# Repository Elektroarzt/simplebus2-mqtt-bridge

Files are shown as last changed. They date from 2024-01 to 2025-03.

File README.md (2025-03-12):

# Simplebus2 MQTT Bridge 

### Table of contents
[1. Overview](#Overview)  
[2. Software](#Software)  
[3. ESPhome](#ESPhome)  
[4. Hardware](#Hardware)  
[5. Mechanics](#Mechanics)  
[6. Disclaimer](#Disclaimer)  
[7. Credits](#Credits) 

## Overview

This project focuses on integrating Comelit intercom systems running the Simplebus2 protocol into a Smart Home, typically equipped with an MQTT broker for information exchange. The following functions have been implemented:

-   Doorbell signal main entrance
-   Doorbell signal apartment door
-   Opening main entrance door
-   Ring-to-Open (automatic opening)
-   WiFi Manager
-   Configuration via Web Interface and MQTT
-   Teach-in of intercom adress
-   OTA updates

Bridge front
Bridge front PCBA
Bridge connector

## Software

### Configuration

A short push on the button (SW1) starts the configuration mode and the bridge opens a WiFi access point named "Config_MQTT_SimpleBus2" for 4 minutes. After connecting to this access point from any device, the following main menu will be shown. If the configured network can't be found or is out of range, the configuration mode will also be launched. The activated configuration mode is signaled by the LED. Alternatively the configuration mode can be started via MQTT.

WiFi manager main menu

After selecting "Configure WiFi" the credentials of the bridge and hardware / firmware configuration can be edited:

WiFi manager configuration

Keep in mind that the ESP32 is not equipped with 5GHz WiFi, only 2,4GHz will work.
The web interface is not supported by every browser in all functions (e.g. firmware update), for best compatibility use Chrome or Edge.

### Hardware tuning
"gain" and "voltage level" are parameters to tune in to the specific installation circumstances depending on cable lenght and resistance of the signal path where gain is the factor the OPV amplifies the line signal at the input and level is the threshold of the comparator before the S2 signal goes to the ESP32s GPIO. A gain of 20 and a voltage level of 600 works good from tests in a building with about 20m cable lenght.

### Open Automation
If selected, the automatic opening of the door after receiving a ring signal is possible. This has to be additionally activated and configured via MQTT. If not selected, the automatic open funcionality is completely disabled.

### Firmware update
The option "Update" in the main menu shows a dialog where a .bin file can be uploaded over the air. This is a good option if the bridge is buried in the switch box. The existing configuration will be kept.

### Adress adjustment
Each intercom unit has its own 8-bits address, which is configured via an 8-way DIP switch during installation. See the interior of your Comelit intercom with the DIP switch in red and translate the bits to your corresponding decimal number, which is usually your appartement or floor number. In some intercoms the DIP-switch can be found on the back, in others you need to open the housing. The address DIP switch is marked S1 and follows LSB logic like in the following table:

 Switch No.| 1 | 2 | 3 | 4 |  5 |  6 |  7 |  8  |
 --------- |:-:|:-:|:-:|:-:|:--:|:--:|:--:|:---:|
 Value     | 1 | 2 | 4 | 8 | 16 | 32 | 64 | 128 |

DIP switch panel

The above intercom for example is addressed to 12.

The adress of the intercom can be easiest teached by pressing the button (SW1) for 3...4s. The bridge will acknowledge with 2x blinking the LED and is then ready to be teached by the next ring that occurs on the bus in the next 3 minutes. The LED will stay on in this time. If the adress has successfully teached in, the LED shuts off and the bridge listens and talks from now on to this specific adress. Alternatively the teach-in process can be started via MQTT. As a third way the choice of the intercom adress can be done manually in the web interface.

### MQTT data structure
**Published topics**

 Topic                          | Values         | Notes
 ------------------------------ |:--------------:| ---------------------------------------------------
 SimpleBus/FloorDoor            | ON             | bell rings on floor door of apartement
 SimpleBus/EntryDoor            | ON             | bell rings on entry door of building
 SimpleBus/Reboot               | ON             | bridge has booted and is listening
 SimpleBus/RingToOpenStatus     | ON / OFF       | 'ring to open' status is on or off
 SimpleBus/RingToOpenOpened     | ON             | is sent if 'ring to open' function opened the door automatically
 SimpleBus/Heartbeat            | ON             | sent every 5min to show online status

**Subscribed topics**

 Topic                          | Values         | Notes
 ------------------------------ |:--------------:| ---------------------------------------------------
 SimpleBus/OpenDoor             | ON             | open the door
 SimpleBus/RingToOpen           | ON / OFF       | activate 'ring to open' (40 minutes default, automatically shut off after bell ring)
 SimpleBus/SetRingToOpenTime    | 1 ... 1440     | activate 'ring to open' for x minutes (max. 24hrs)
 SimpleBus/SetGain              | 2 ... 40       | set gain factor of the amplifier U4 (20 default)
 SimpleBus/SetComparatorVoltage | 100 ... 1500   | set threshold of the comparator U6 to x millivolts, e.g. 600 (default)
 SimpleBus/StartConfigMode      | ON             | start web configuration portal on IP address 192.168.4.1
 SimpleBus/StartTeachIn         | ON / OFF       | ON activates teach-in routine, learns intercom address from the bus; OFF cancels the teaching process
 SimpleBus/Restart              | ON             | restarts the ESP32

### Dependencies
The following components are required to build the firmware. Other versions may also work but are not tested.

 | Component    | Version     | Link                                             |
 | ------------ | :---------- | ------------------------------------------------ |
 | EEPROM       | 2.0.0       | default Arduino                                  |
 | WiFi         | 2.0.0       | default Arduino                                  |
 | Wire         | 2.0.0       | default Arduino                                  |
 | MultiButton  | 1.2.0       | https://github.com/poelstra/arduino-multi-button |
 | Debounce     | 1.2.0       | https://github.com/wkoch/Debounce                |
 | PubSubClient | 2.8         | https://github.com/knolleary/pubsubclient        |
 | WiFiManager  | 2.0.16-rc.2 | https://github.com/tzapu/WiFiManager             |

## ESPhome
If you feel more familiar with ESPhome instead of MQTT give [this companion project](https://github.com/se-bastiaan/esphome-simplebus2) a try. It is based on the hardware of this project and allows for easy integration in Home Assistant. Many thanks to [se-bastiaan](https://github.com/se-bastiaan) for his fabulous work!

## Hardware

The electronics draw power from the bus voltage and require no additional power source. A Seeed Studio XIAO ESP32C3 serves as the controller board.

schematics V2 2

### Expansion pin header J2
For future use this pin header can connect to a piggy-back. The M2.5 hole in the neighborhood can be used to secure a sandwich PCBA.

 Signal Name   | Pin  | Notes
 ------------- |:----:| --------------------------------------------------------------------------------------
 D6            | 1    | GPIO 21 of ESP32 (D6 of XIAO module pinout)
 3V3           | 2    | directly connected to 3.3V plane
 D3            | 3    | GPIO 5 of ESP32 (D3 of XIAO module pinout, outputs PWM signal at boot, strapping pin)
 GND           | 4    | directly connected to GND plane
 
### Debug pin header J3
Meant for debugging, header can be populated optionally. The following signals can be measured against GND:

 Signal Name   | Pin  | Notes
 ------------- |:----:| ----------------------------------------------------------------------------
 D1            | 1    | voltage divider 1, reference voltage of OPV filter stage 1 ('gain' parameter)
 S2            | 2    | cleaned payload signal of Simplebus2
 D2            | 3    | voltage divider 2, reference voltage of comparator ('level' parameter)
 GND           | 4    | directly connected to GND plane

### Filter
In the schematics two filters can be found, one low pass (C5 and R5) and one high pass sallen key active filter with a gain of 2. Between those two filters there is signal amplifier which can be set individually to compensate for a long bus wire. The goal is to filter and amplify the incoming 25 kHz signal.

R1 and R11 are alternative positions to select signal conditioning by hardware (comparator U6) or direct input of the signal into the ESP32. In the second case the firmware should do the signal conditioning via DSP routines or similar. At the moment the DSP option is not implemented in the firmware and is meant for future use, so option "OPV" is default. To change this, desolder R11 and close R1 with a solder drop or a 0Ohms resistor.

## Printed Circuit Board (PCB)

The PCB was designed with KiCAD using through-hole technology (THT) and surface-mount device technology (SMD) to match the limited space requirements. Top layer is 3,3V plane and bottom is GND plane.
If someone is interested in a complete bridge including all parts (PCBA, ESP32, housing, etc.) you can contact me under elektroarzt@digital-filestore.de.

PCB Layout front

## Mechanics

The entire electronics assembly fits into a flush-mounted switch box, resulting in a streamlined enclosure. The latch was designed as a snap closure, eliminating the need for additional mechanical components beyond the housing shells.



A second option for the housing is a DIN rail enclosure. For this, I have created an alternative bottom shell with a builtin clip that can be directly clicked onto a DIN rail. It should not be printed in PLA, use a somewhat flexible filament like PETG. Otherwise, there is a risk of cracking the clip if released from the DIN rail again. The top part of the housing is identical to the flush-mounted version.

Bottom DIN Rail Mount
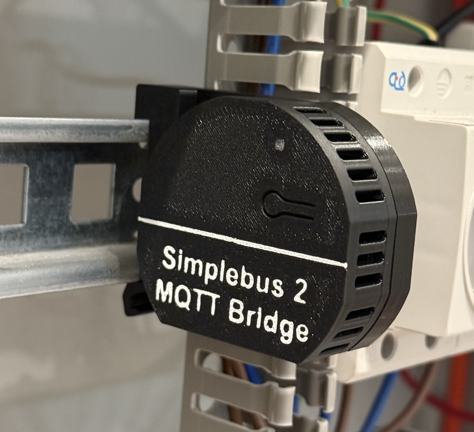
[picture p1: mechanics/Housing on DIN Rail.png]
Bottom DIN Rail Mount


### Antenna
The antenna is mounted inside the housing with adhesive tape. A small cable channel exists for the antenna cable within the housing. Be careful while inserting the PCB in the housing not to shear off the antenna cable if it is not inserted properly into the cable channel.

Bridge Antenna

### USB connector
The USB-C socket is externally routed, allowing for easy firmware updates.

### LED and button
The onboard LED features a simple light guide, making it visible externally when the housing is closed. The onboard button is operated with a small axis embedded in the housing.

### Housing
The housing was designed in Autodesk Fusion 360 and 3D-printed in three colors on Bambu Lab P1S printer:
-   LED diffuser: transparent filament
-   Housing: black filament
-   Labeling: white filament



For the type of filament every material is suitable that has low stringing tendency. PETG works for me without needing supports. 0.2mm layer height does a good job on a 0.4mm standard nozzle.

Bambu Lab project

## Disclaimer
> :warning: **WARNING**: You may only **USE THIS PROJECT AT YOUR OWN RISK**. The
  information provided is meant to be helpful but may contain errors or may be
  misinterpreted. Neither myself nor any of the contributors to this project
  provide any warranty or will assume any responsibility for any damage you
  cause yourself or others by using this project.

## Credits
The project originated from the excellent foundational work on the Simplebus2 protocol by [plusvic](https://github.com/plusvic). These fundamentals will not be reiterated and can be found [here](https://github.com/plusvic/simplebus2-intercom).

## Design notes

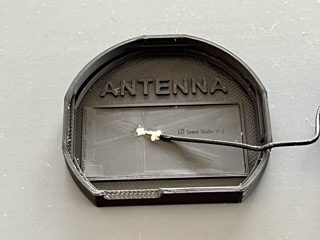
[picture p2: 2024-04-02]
hardware/Bridge antenna.jpeg

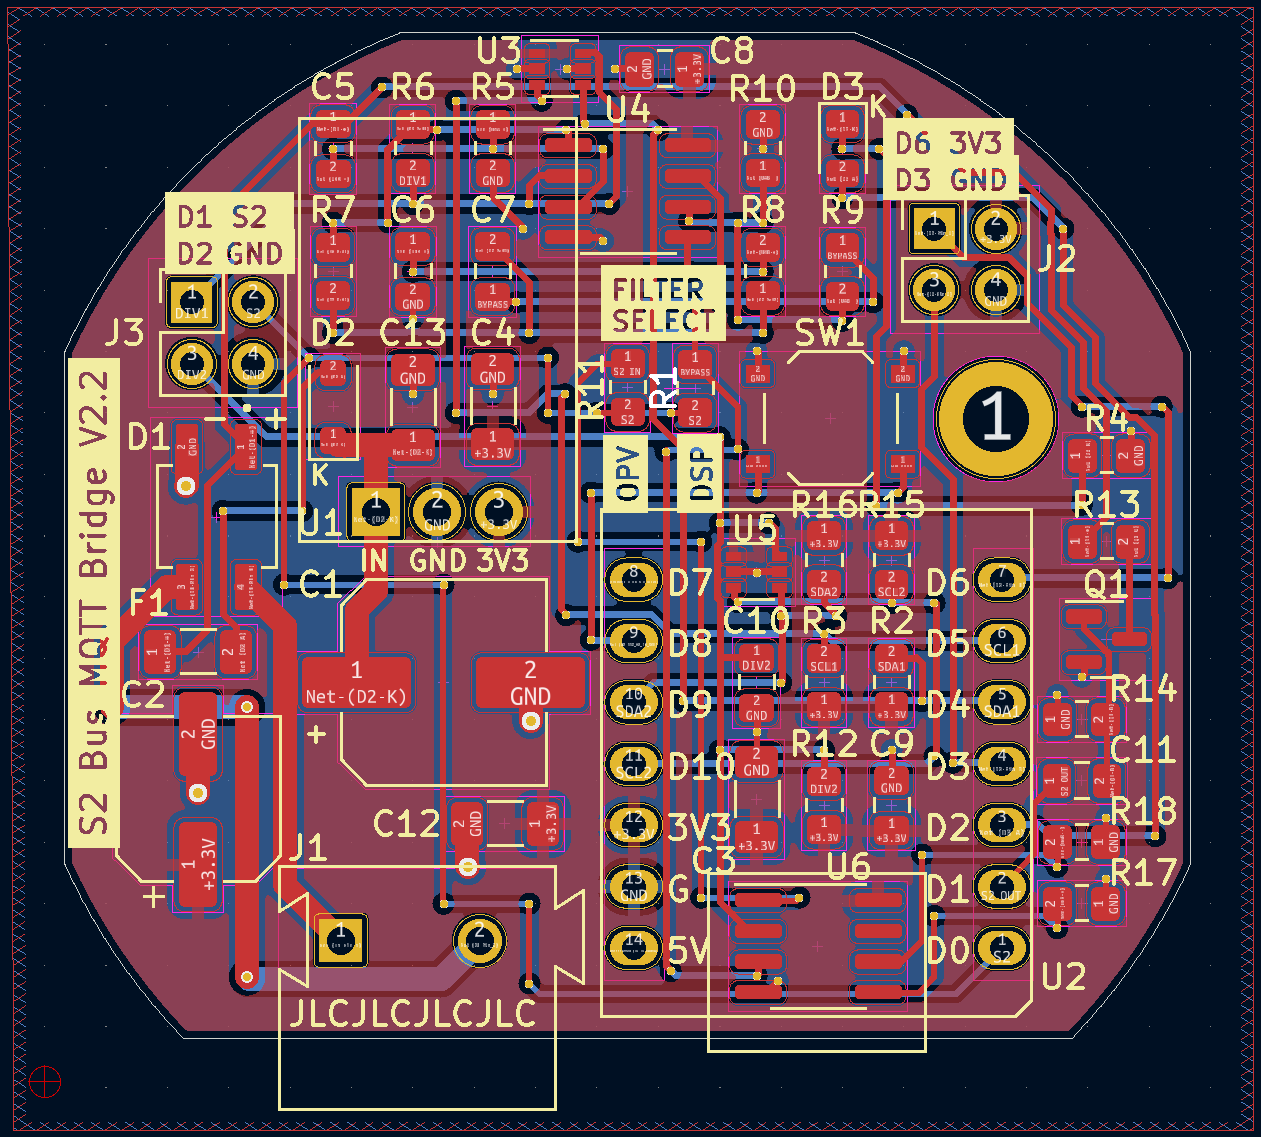
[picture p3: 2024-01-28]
hardware/Layout front V2.2.png

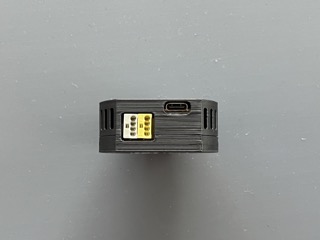
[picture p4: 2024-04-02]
hardware/Bridge connector.jpeg

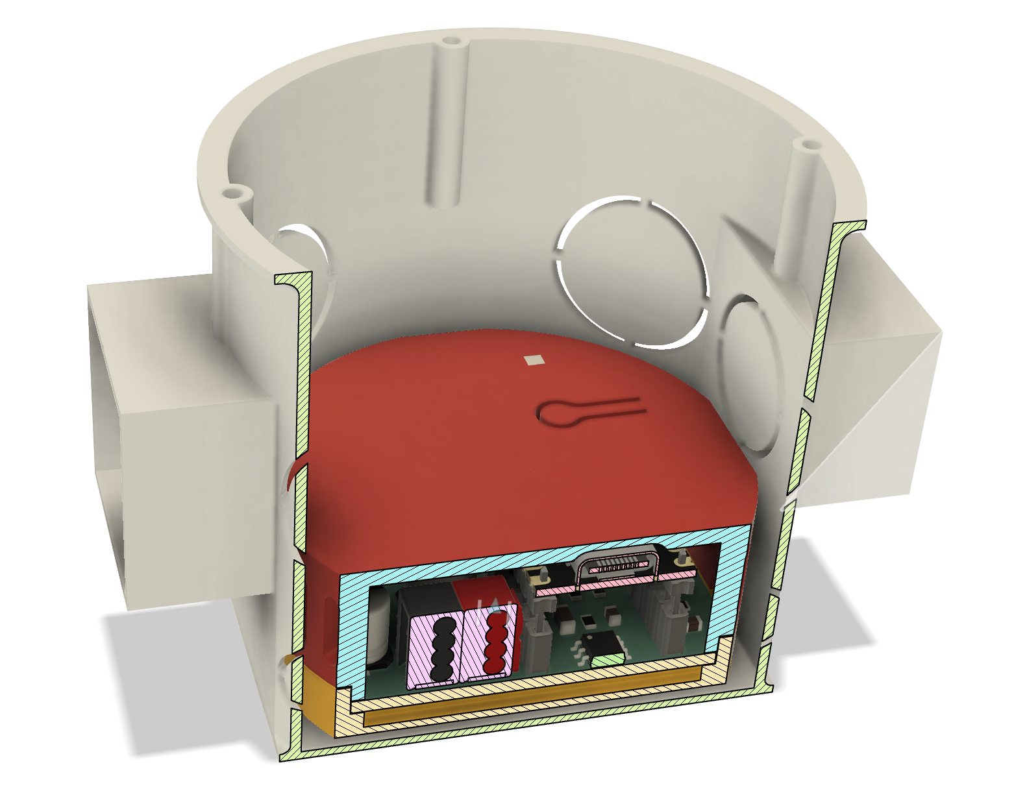
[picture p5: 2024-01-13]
mechanics/Housing in flush mounted switch box.png

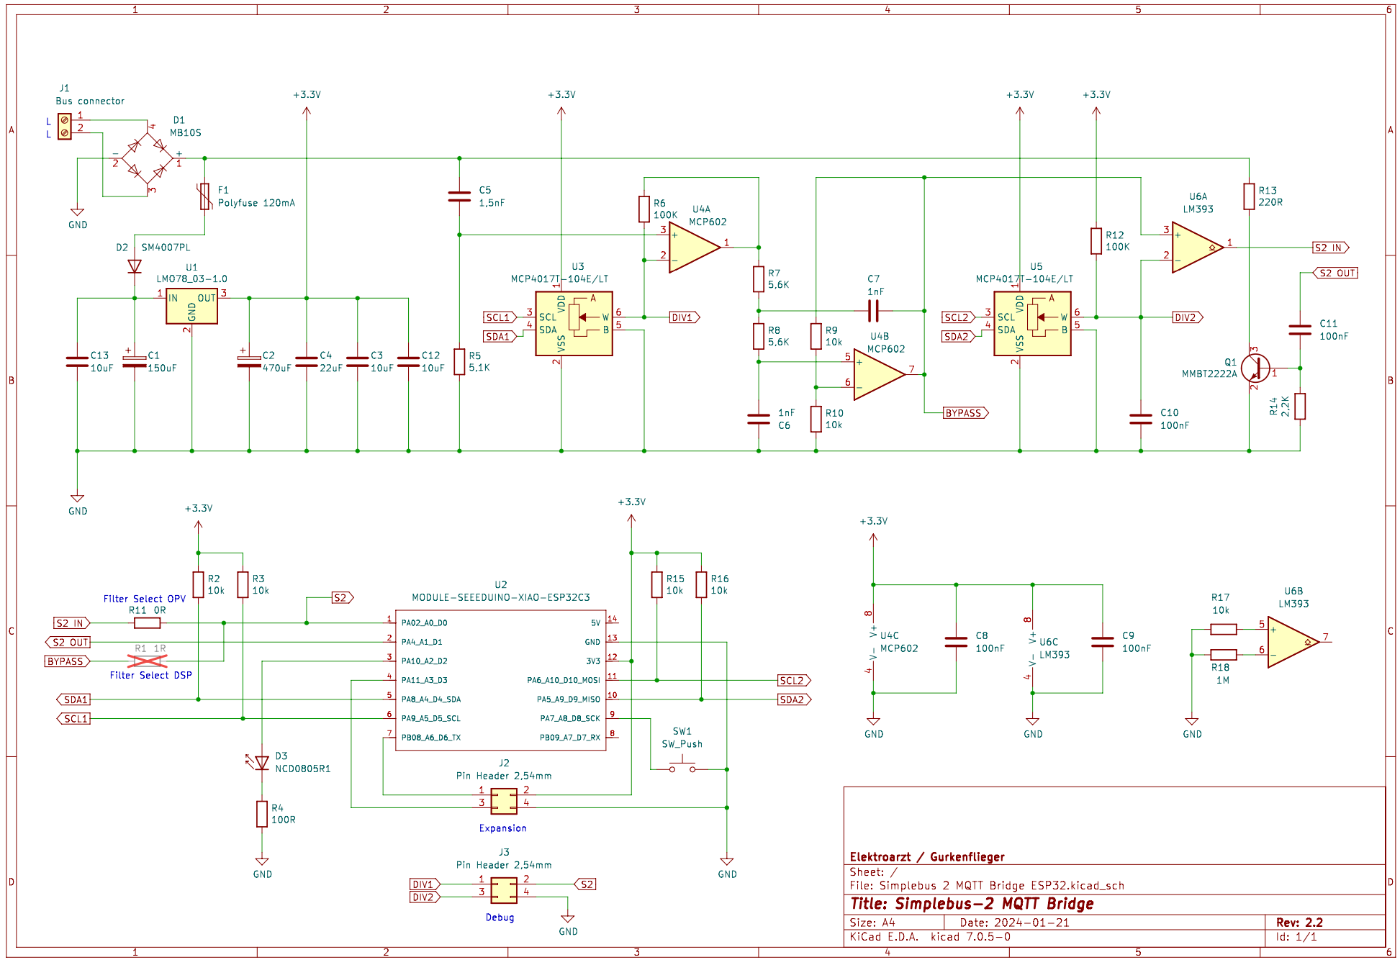
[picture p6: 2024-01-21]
hardware/schematics V2.2.png

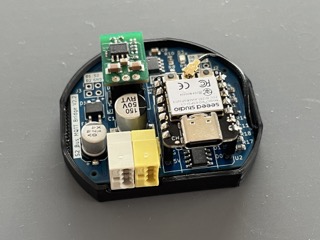
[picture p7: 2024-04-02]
hardware/Bridge front PCBA.jpeg

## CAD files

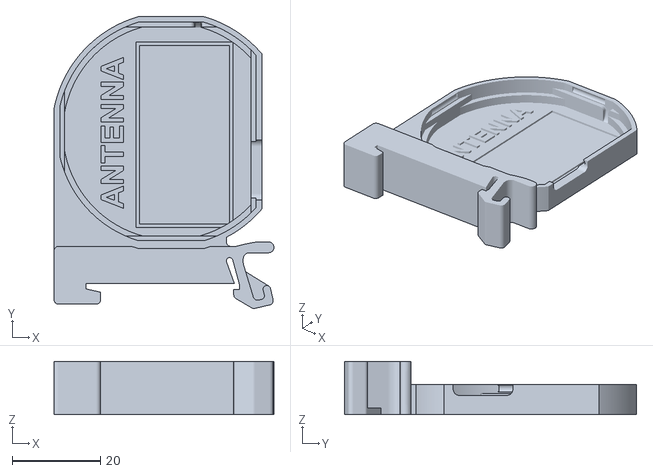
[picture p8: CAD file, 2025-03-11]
mechanics/Housing Bottom Shell DIN Rail Mount.stl
49.7 x 66.1 x 12.0

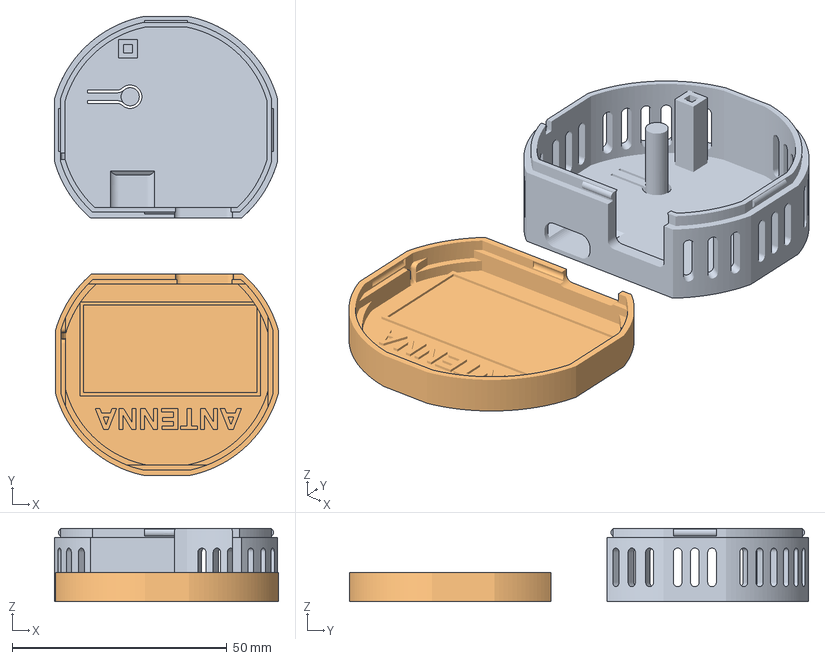
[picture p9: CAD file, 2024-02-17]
mechanics/Simplebus2 MQTT Bridge Bambu Lab Project.3mf
52.2 x 107.0 x 17.1 mm
Top Shell
Bottom Shell

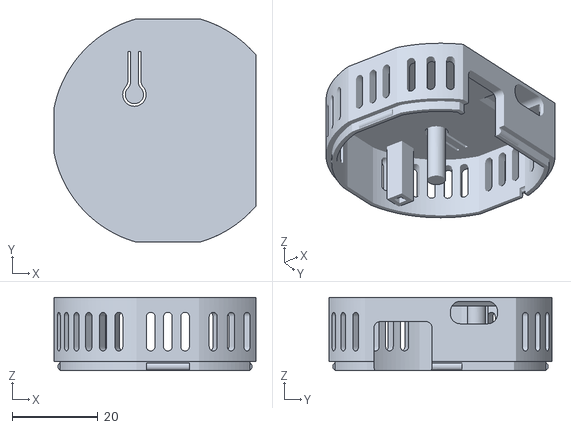
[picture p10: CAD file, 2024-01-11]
mechanics/Housing Top Shell.stl
47.0 x 52.0 x 17.1

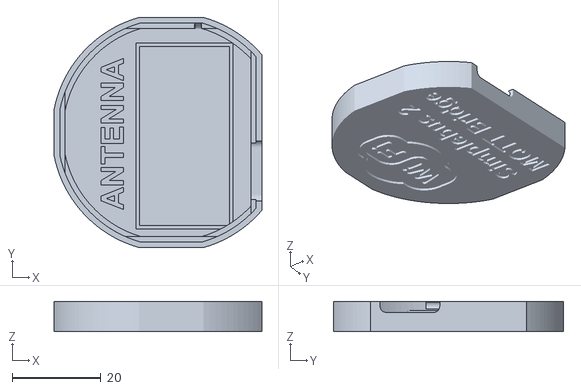
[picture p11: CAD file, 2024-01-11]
mechanics/Housing Bottom Shell Flush Mounted.stl
47.0 x 52.0 x 6.80

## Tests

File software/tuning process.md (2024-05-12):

# Tuning process for gain and threshold parameters

If you have no oscilloscope to measure the telegram signaling, you are some kind of blind and it could get a game of testing to find out the right combination of gain and threshold for your specific environment. In this case I would go this way:

1. Be sure to have an easy way on your mobile phone to tune the parameters gain and threshold via MQTT and to see the recognition of the bell telegrams. I used Node Red, but you could also use an MQTT analyzer app on your phone.

2. Check if you see a heartbeat on MQTT topic SimpleBus/Heartbeat after powering the bridge to secure your MQTT chain is online before making tests.

3. Start your tests at the floor door (apartment). Stand at the bell switch and make tests with your mobile phone in the hand to tune the parameters after each failure. For the start tune to 5/200 (gain/threshold) and go up with the threshold from 200mV up to max. 1000mV in steps of 50 for each test. If you find no recognition on MQTT topic SimpleBus/FloorDoor, start again at threshold 200 with gain rised in steps of 5 and so on until you get ON on MQTT.

4. Now make some tests at the entry door (MQTT topic SimpleBus/EntryDoor). The cable length is much longer, so the damping is higher for the telegram. The gain has to be also a bit higher for reliable recognition probably. So if you encounter a working bell signal on the floor door, it could be you have to add some gain for the entry door.

5. As a rule of thumb, the higher the gain is set, the higher you have to set the threshold, as the noise on the line is always amplified too (signal/noise ratio).

With this setup you should be able to find the right setting within short time.

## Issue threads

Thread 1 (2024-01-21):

PCBA

Elektroarzt, 2024-01-21:
Upload is done for now. If someone is interested in a complete bridge including all parts (PCBA, ESP32, housing, etc.) you can contact me under elektroarzt@digital-filestore.de.

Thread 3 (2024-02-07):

Adding support for audio/video

sashahilton00, 2024-02-07:
Hi,

Opening an issue here after @Elektroarzt and I emailed for a bit. Relevant parts of the the email trail pasted below:

> @sashahilton00 - Out of interest did you get anywhere with the audio/video component? From what I’ve read it’s some sort of composite video, I’m wondering if it would be possible to add a decoder chip and create an RTSP server on the device when the camera is activated, then send the server address over MQTT to enable a remote feed.

> @Elektroarzt - Concerning the video option, we (Gurkenflieger and me) did not investigate yet but I’d love such a feature. This would be a Piggy-Back on the existing PCB or a complete new design with maybe 4 layers instead of 2, as the current design is at the lower end of JLCPCBs 2 layer design rules in terms of  trace width, micro vias and so on.

> @sashahilton00 - For the audio/video I’ve done a small amount of reading - it seems to be using some sort of analog audio and NTSC/PAL video on the bus from what I can tell. The latter would need a dedicated decoder chip that fed digital out into the ESP32 via i2s, need to investigate the audio. The comelit-simplebus1 project on GitHub may offer some insight, as I’d be surprised if they’d changed much between the two.
You may be right about the 4 layers being needed, though it would be good to keep it as 2 to keep costs down and allow people with a home setup to manufacture it. Also one would need to give some consideration to power draw as I’m sure video decoding will use a fair bit more than the current system.

> @Elektroarzt - From what I read, the video feature would bring necessity for an external PSRAM attached to the ESP, as the 400kB or so would’t be sufficient to store a single frame in the onboard RAM.

> @sashahilton00 - Both https://www.espboards.dev/blog/esp32-soc-options/ and https://gist.github.com/sekcompsci/2bf39e715d5fe47579fa184fa819f421 seem to suggest that the ESP32-S2 has both an internal ADC and DAC. My PCB skills are a little rusty, but looking at a similar project (https://github.com/vvigilante/comelit-simplebus1), it looks as though that’s what vvigilante has done - used the internal ADC/DACs for the audio with a potentiometer to allow for manual adjustment (could be neat if this were a digital potentiometer) - I don’t have an oscilloscope to measure, but vvigilante mentions that peak to peak amplitude is approximately 2.5v.
My thinking is that one could incorporate the analogue write/analogue write enable circuitry into your design, and at the same time switch from the Seeed Studio XIAO ESP32C3 to something like the Adafruit QT Py ESP32-S2 (https://shop.pimoroni.com/products/adafruit-qt-py-esp32-s2-wifi-dev-board-with-ufl-antenna-port-stemma-qt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), which keeps the xiao footprint, type c and external antenna, or equally one could move to having the esp32 soldered directly by JLC or similar (eg. ESP32-S2-MINI-2U-N4), and including the type C connector manually.
One thought I did have if one goes down the soldered board route, is to make the type C connector (and possibly the bus connector) vertical, eg. https://jlcpcb.com/partdetail/Xunpu-TYPEC_300ABCP16H175/C5454935, as when in the standard euro switch box the USB would then be accessible without needing to remove the device for firmware updates.
If one went down this route it looks as though esp-adf (https://github.com/espressif/esp-adf) would provide the necessary support to implement two way audio streaming (have a look at the following for an RTSP implementation: https://github.com/espressif/esp-adf/tree/48dea7711391e0abf00c65aca18557572fc5189a/examples/protocols/esp-rtsp), where a ring of the bell would set up the rtsp server and send the ringing MQTT message, whilst the client if a microphone is available can send an RTSP address in an MQTT message for the microphone stream. There’s also RTC/VoIP possibilities if that’s preferred.
If that sounds of interest and you’re happy to modify the PCB to use an S2 variant chip with the ADC/DAC wired up to the bus, I’d be happy to get JLC to make me up a board and see if I can write some software to get two way audio working.

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

sashahilton00, 2024-02-07:
@Gurkenflieger if you have any thoughts they would be most welcome.

Having done some more reading up today on the ESP32 and video capture, it looks as though it will be a stretch to manage it. If you have any insights as to the video format that Comelit is using that would be great, everything I read suggeests it's NTSC/PAL.

With that in mind, the ESP32 has support for the ESP32-CAM module, which seems to support an 8 or 16 bit DVP image sensor. There are also low power PAL/NTSC decoder chips available (eg. TVP5150AM1), which output the same 8-bit YCbCr 4:2:2 as the esp32 cam to my knowledge. The esp32 apparently has a 20MHz limit on the pixel clock from the sensor, whilst PAL/NTSC requires a 27Mhz clock, though after a bit of searching theres [this](https://esp32.com/viewtopic.php?t=2564#p12309) rather neat workaround by the looks of it from `ESP_igrr`, which uses a frequency divider and two octal latching ICs to convert the 8-bit 27Mhz stream into a 16 bit 14.5Mhz stream, essentially halving the overhead.

However, this is where I'm not sure the video component is solvable - the raw video stream is too large to stream (as highlighted [here](https://github.com/wooky/esp32-analog-video-over-wifi)), if you've got any thoughts as to whether this is doable without building a fully fledged streaming SBC, I'm all ears, though dealing with video decoding/encoding feels like it's getting a bit beyond the scope of a simple retrofit device.

Elektroarzt, 2024-02-08:
@sashahilton00 I can say that the video option would be out of my comfort zone concerning the RF layout and debugging. If you like to contribute and go for a prototype with the audio part, you are welcome. I then could integrate in the PCB, if tests run ok.

Elektroarzt, 2024-09-07:
Closed due to inactivity

Closed 2024-09-07.

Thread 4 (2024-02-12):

I2C communication not working correctly

Elektroarzt, 2024-02-12:
The voltage dividers for the OPVs are programmable via I2C potentiometers. In the current firmware the communication on bus 1 and 2 seem not to work.

Gurkenflieger, 2024-02-13:
Fixed in recent commit

Closed 2024-02-13.

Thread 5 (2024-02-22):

Recognition of entry door ring not working

alexdetsch, 2024-02-22:
I have the problem that the doorbell at the front door is not recognized. However, ringing the doorbell at the apartment door and opening the front door works without any problems. I have already checked the signals with Elektroarzt and they should actually be correct. The message in the signal from the front door is also correct (my intercom system also rings). Following is a picture of the oscilloscope.
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

Yellow is the signal in front of the comparator, blue behind it (at S2). The firmware is from 2024-02-07 15:19. The gain is currently set to 80 (much too high actually, I know), the voltage threshold to 200. I have tried gain in the range of 7-80 and voltage threshold of 100-200, as well as with and without activated "filter"-checkbox.

Gurkenflieger, 2024-02-23:
This could be a Timing Problem. Habe you tested RingToOpen? Does it work. I can imagine that the mqtt send command is too early and the power is insufficient directly after the ring command.

alexdetsch, 2024-02-23:
I tried that now, but it didn't work (both with and without attached loudspeaker).
All my other attempts the other days were without the loudspeaker handheld, so I think there wasn't much of a voltage drop while ringing. And I don't think there should be any difference between the front door and the apartment door from the voltage drop regard?

Gurkenflieger, 2024-02-23:
You can debug the Software with an attached pc in the stdout. There should be debug messages which are commented out. They print the single recognized bits. Is it possible to comment them in ?

alexdetsch, 2024-02-23:
I can try, but unfortunately I can't find all the dependencies. It would be nice if you could add a few more details about which specific library is meant (GitHub link?). Currently I can't find the debounce library.

Gurkenflieger, 2024-02-23:
Sry here is the github link of the debounce lib.
 https://github.com/wkoch/Debounce i'm using v1.2

alexdetsch, 2024-02-23:
Ok, the address and msgCode is recognized correctly:
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
So it's probably an easy fix :) I'll debug a little bit

alexdetsch, 2024-02-23:
Yes, I had everything correct.
The bug is in [L464](https://github.com/Elektroarzt/simplebus2-mqtt-bridge/blob/main/software/main.cpp#L464). When messageCode 48 is sent, there is just a break. I removed it and now it works flawlessly. Maybe it worked for you because you have an other Intercom? My entry door intercom send msgCode 48 (as shown in the image above) instead of 50.

Gurkenflieger, 2024-02-23:
Thanks, of course intercoms without a screen hava an other message.  I will update the code soon. Thanks for the work!

Elektroarzt, 2024-02-23:
By the way ... what gain and threshold values are working for you after the fix?

alexdetsch, 2024-02-24:
Currently I still have 80 gain and 150 voltage threshold cause I didn't bothered with them anymore after it worked finally. But initially the two functions ring on apartment door and open entry door worked with the default values.

I already built the module behind my Intercom, so its kinda complex to get it in configuration mode when I'm not wrong (which eliminates the advantage of remote firmware updates for me, because I still need physical access).
Or is there currently a way to activate the configuration mode remotely? I'm thinking about implementing an activate-conf-mode-over-mqtt-feature, what do you think about that?

Elektroarzt, 2024-02-24:
There is no way for remote activation currently. What do you think of conf-over-MQTT instead of activating the conf mode or both? Of course one has to initially config via Web Interface. But to change some values it could be cool to have all parameters at MQTT-hand.

alexdetsch, 2024-02-24:
Above I meant to activate the conf mode over MQTT. I also implemented it in my fork already to tinker around (but didn't tested it yet cause of laziness to take the intercom apart again). But you're right, having the config values (gain, threshold, filter) on hand via MQTT is also a very nice idea! (don't know why I didn't think of this very obvious idea 😶‍🌫️)

Gurkenflieger, 2024-02-25:
Activating the config mode with mqtt is a good idea 👍.

richardneitzke, 2024-02-28:
> it worked all the way down to gain=1 and threshold=1 and at this point I'm not sure if the values are set correctly (I had 8 tries from gain=80 and threshold=200)

@alexdetsch maybe your settings have no effect at all, that’s what I ran into (#7)

Gurkenflieger, 2024-02-29:
Maybe the resistors are stuck at a wrong state and the reset does not work as intended. I can add a send command to reset the resistors. Will update the code soon.

Gurkenflieger, 2024-04-02:
It should work now with 600mV comparator voltage and 20 Gain. Can you test it?

Closed 2024-04-02.

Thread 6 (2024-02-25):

Add setup with MQTT and start webconfig with MQTT

Gurkenflieger, 2024-02-25:
-Add setup of filter, gain and comparator voltage with    mqtt.
-Start Webinterface with MQTT.
-Improve MQTT send command.

Elektroarzt, 2024-02-25:
If you put your hands on the web interface function and can reproduce it, could you have a look at the exit procedure? From time to time I experience the LED not going off after changing parameters and leaving the web interface via save button. I then shortly disconnect bus power to return to normal operation. Could be critical, if the config is started by MQTT and can't be exited remotely.

Gurkenflieger, 2024-04-02:
Now implemented with improved MQTT commands.

Closed 2024-04-02.

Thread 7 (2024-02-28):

Changing the level/threshold parameters has no effect

richardneitzke, 2024-02-28:
I'm using a V2.2 bridge provided by @Elektroarzt and so far I haven't managed to make things work. I switched to the latest firmware (3b4bd75) for debugging and noticed that the "level" (`compVoltLvl`) parameter does not seem to have any effect on the comparator reference voltage (D2).

The level parameter appeared to be working with the original firmware that shipped with the bridge. I haven't actually measured it but changing it seemed to have an effect on the detection quality.

I measure an average of about 1.03V on D2, no matter whether the level is set to 150mV (`setPotValue(6)`) or 500mV (`setPotValue(22)`):

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

richardneitzke, 2024-02-28:
I also checked whether changing the "gain" parameter has any noticeable difference on the comparator input (measured at the "R1-1" pad) and it seems like that isn't the case either. The level of the signal at that pad is about the same when I set gain to 5 vs. 50.

This indicates that this isn't specific to the "level" parameter but rather an issue with the connection to the MCP4017 potentiometer?

richardneitzke, 2024-02-29:
@Gurkenflieger I only have a very vague idea of what I'm doing but I made some changes and the voltage on D2 is now in the ballpark of what I configure it to. I think this is still not the correct reset sequence (it should have another start bit after the 9 "1" bits).

In `setupI2C(int)`:

```C++
Wire.begin(sdaPin, sclPin, I2C_FREQ);
Wire.beginTransmission(0b111111111);
Wire.endTransmission();
```

At the end of `setPotValue(byte)`:

```C++
Wire.end();
```

Gurkenflieger, 2024-03-01:
Which version did you use? already implemented an almost similar fix in the recent Version.
Wire.beginTransmission(0xFF);
 Wire.endTransmission();
 this worked with my stuck Resistor.

richardneitzke, 2024-03-02:
> Which version did you use? already implemented an almost similar fix in the recent Version.

I referenced the commit in my initial message, seems like it contained the fix you referenced.

> can you test this?

I'll test it later, the code I posted seemed to do the trick so I assume yours will also work 👍

Gurkenflieger, 2024-04-02:
Wirh the new commit the values will change.

Closed 2024-04-02.

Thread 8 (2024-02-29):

No pulses on S2

richardneitzke, 2024-02-29:
When I ring the floor door and observe the comparator input ("R1-1") and the payload signal (S2 debug pin) I don't see a clean PWM signal on S2. Right now, the firmware is unable to decode messages from signals like this. I could try to make this work in software but I was hoping that we can find a way to have clean signals for installations like mine.

Here's the full signal, C1 being the payload signal and C2 the comparator input as reference. Notice how the burst is not oscillating cleanly on the comparator input and barely oscillating on S2:

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

| Two bursts as an example | Closeup of a single burst |
| -- | -- |
| 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 | 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 |

Here is a closeup of the acknowledgement bursts (presumably by the main unit). These are basically perfect. I optimized my gain/threshold values for these pulses (raising them to about 500mV at the comparator input as recommended by @Elektroarzt):

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

 (Sorry for the photos, my scope stopped accepting USB drives...)

Gurkenflieger, 2024-03-01:
Have you tried disabling the Filter?

richardneitzke, 2024-03-02:
> Have you tried disabling the Filter?

No, I haven't tried to bypass the HW filter.

> I uploaded a new version. Can you test this one?

The measurements above were taken on a [modified FW](https://github.com/Elektroarzt/simplebus2-mqtt-bridge/issues/7#issuecomment-1971938850) that was almost identical to the new version (the I2C connection to the MCP4017's seemed to work). I don't think using the new version would make a difference but I can try?

> Does your intercom has a screen?

Yes 👍

> I Also will change the interrupt detection from rising to Falling or Change. This could fix your problem!

Yes, that would work. I was hoping we would find a HW fix which results in a regular signal. Working around the irregular signal in SW is probably less reliable than adjusting the HW so that it either serves clean bursts or no bursts at all on S2?

Gurkenflieger, 2024-03-02:
Not the hardware filter but the software filter in the webconfig. You can also turn down the Gain. This should help alot!

richardneitzke, 2024-03-02:
Yes, I turned off the software filter 👍 This issue is mostly about the hardware though, wouldn't it be more desirable to ensure a clean signal as opposed to working around the irregular signal in the firmware?

> You can also turn down the Gain. This should help alot!

There's a fairly big delta in amplitude between the signal from my intercom and the signal from the main unit. I tweaked the gain value so that I can reliably detect signals from the main unit (as seen in the last image of my initial post). If I reduce the gain I would most likely lose the ability to detect these, right?

Gurkenflieger, 2024-03-02:
Ah you should tweak the gain and comparator voltage not on the acknowledge bursts but on the message itself. The acknowledge is always way higher than the message itself. The software only looks for the message not the acknowledge. Which values did you set for the gain? The could be way too high and induce noise.  Try gain 10 and 200mV. Then you can also use the debut messages and comment thwm in.

richardneitzke, 2024-03-02:
> Ah you should tweak the gain and comparator voltage not on the acknowledge bursts but on the message itself. [...] The software only looks for the message not the acknowledge.

I realise that, but the message I measured above comes from my intercom. I would like to be notified of messages from my intercom (in case somebody rings at my apartment door) as well as messages from the main unit (in case somebody rings at the house door downstairs). As you write, there is a big difference in amplitude between the two. Yet, I want to be able to decode both. If I reduce the gain, wouldn't I lose the ability to decode messages from the main unit (which are currently decoded perfectly, see the acknowledgement bursts which come from the main unit in the last image)?.

>  The acknowledge is always way higher than the message itself.

At least in my installation that doesn't seem to be the case when the message comes from the intercom itself. I assume the acknowledgement comes from the main unit (which is why the amplitude is much lower in that case).

> A clean PWM is not necessary. The software measures time between too high signals (in future release between too pin changes). The measured time (pause time) determines if it's a 0 or 1 or a start bit.

Huh, this puzzles me. Could you please elaborate? If I understand the current iteration of the software correctly it _does_ rely on a clean PWM signal. My understanding is that the software would interpret a noisy PWM burst such as the one I posted above ("Closeup of a single burst") as a "0" because the burst itself contains a ~2.5ms "pause" between two rising edges.

There surely are ways to clean up the signal in software but I would only go there if there are no ways to improve the signal quality itself.

Gurkenflieger, 2024-03-02:
No only if the filter is enabled a more or less clean PWM signal is necessary. Without the software filter it measures the time between two bursts or the time between two high pins. The PWM itself does not matter i just need a high signal.

richardneitzke, 2024-03-02:
> No only if the filter is enabled a more or less clean PWM signal is necessary. Without the software filter it measures the time between two bursts or the time between two high pins. Its just ja timer that resets if a high signal is detected. If the timer reaches a certain value it determines if its a 0 or 1 or start bit.

This is a 3ms burst, by itself it shouldn't be decoded into a 0/1. My understanding is that the current firmware measures the pauses between rising edges, that's what you describe as well (_"a timer that resets if a high signal is detected"_). This burst has a rising edge at the trigger point and about 2.4ms after the trigger point. Wouldn't the firmware decode this as a 0-bit because the pause is between 2ms...4.9ms?

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

richardneitzke, 2024-03-02:
Just to reiterate: I realize that this can be fixed in software by introducing stricter timing requirements and also taking falling edges into account. But to me the underlying issue appears to be on the hardware-side and we’d be better off fixing it there instead. It seems like that would result in a more stable system overall.

Gurkenflieger, 2024-03-02:
Now i see your problem. Where is the Bridge connected? Because your Signal is so high its near the main unit and not the Screen? Try turning down your Gain and turning up your comparator voltage to 600-800mV. I will revisit the problem.

richardneitzke, 2024-03-02:
I think there’s still a misunderstanding, so I’ll just repeat 😅

I recorded this when my floor door was rung. The message comes from the intercom unit itself. The acknowledgement comes from the main unit.

The messages from the main unit are decoded fine but I also want to decode the messages from my intercom unit. If I reduce the gain and increase the comparator voltage I won’t be able to decode the messages from the main unit anymore.

Elektroarzt, 2024-03-03:
This is your measuring setup, right?
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

Gurkenflieger, 2024-03-03:
Now i understand your Problem. I dont know if there is an easy hardware solution for the comparator. Like i said the PWM is not necessary and we can easily find a software fix. We can also bypass the comparator which seems to be too slow and check the raw signal with the esp. Bypassing the comparator is already considered in the current design but we have to write software to check the signal at the analog in.

richardneitzke, 2024-03-03:
> This is your measuring setup, right?

@Elektroarzt Yes, that's it 👍

> Can you post the signal from the entry door which needs to be amplified? Which gain did you set?

@Gurkenflieger here's what the signal from the entry door looks like (gain = 1, compVoltLvl = 250):

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

Gurkenflieger, 2024-04-02:
I updated the Code and now my floordoor and on some other intercoms are now working correctly. Can you try it out with the latest firmware. You have to set Gain 20 and 600 mV.

Elektroarzt, 2024-05-28:
Have you seen the how-to for the tuning process I wrote? See [here](https://github.com/Elektroarzt/simplebus2-mqtt-bridge/blob/7138530772fd946b185f70a6c94b0642a4dc3e89/software/tuning%20process.md).

richardneitzke, 2024-05-28:
I had a look at the commits that have been made since I raised the issue and maybe I'm missing something but I don't see any changes that address the underlying issue I described [here](https://github.com/Elektroarzt/simplebus2-mqtt-bridge/issues/8#issuecomment-1974823521)? So I don't think tuning the gain/threshold values would do any good here?

Elektroarzt, 2024-05-29:
The behavior you described is normally caused by too high gain, it's not an issue in the firmware in my opinion. Which gain did you set in the given picture? I can reproduce this beginning from gain around 30. Did you follow the tuning sequence as described?

Gain set to 25:
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

Gain set to 30:
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

richardneitzke, 2024-05-29:
Ah thank you, that makes sense! I don't recall the gain value I used for the picture but I will try tuning it again 👍

Elektroarzt, 2024-05-29:
I saw you've set 1 as gain in one post. This was never an allowed value but was not restricted by the legacy firmwares. Be sure to have the newest firmware running before doing the tests, as it checks for the correct range.

richardneitzke, 2024-05-29:
> I saw you've set 1 as gain in one post. This was never an allowed value but was not restricted by the legacy firmwares. Be sure to have the newest firmware running before doing the tests, as it checks for the correct range.

Thanks for the hint 👍 I assume that most of my settings back then did not actually apply correctly due to the I2C bug. I will try tuning it again on the latest FW.

Closed 2024-04-26.

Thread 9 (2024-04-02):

Your help is needed for standard values for gain and threshold

Elektroarzt, 2024-04-02:
From experience, it was a good decision to equip the values for gain and threshold with digital potentiometers, as there is a signal dependency on every specific installation regarding attenuation on the bus wires. After extensive testing, standard parameters have crystallized for this purpose. With the values of gain at 20 and a threshold of 600mV, the up to now considered systems are operational. If you have a bridge up and running, please be so kind as to reply to this thread whether these settings also work for you, so that we can confirm these values as standards for the community. If they do not work, please write back your working values.
Both can be set easily with the new MQTT commands in the latest firmware or in the web interface (see readme).

Thanks for your support! :wave:

alexdetsch, 2024-04-13:
For me 20/600 is working fine with the latest firmware :)

LaurensdeGraaff, 2024-05-01:
The default is not working for me, I'm still trying to get a working config. Do you have any tips how to find them without a oscilloscope? I flashed it with esp-home, if you have a .bin file I will gladly test the values on the MQTT firmware.

Elektroarzt, 2024-05-02:
The config values 20/600 are tested and working with the Arduino firmware. If you have flashed a 'custom' firmware, there is a completely different algorithm decoding the bus signals. So likely other standard parameters have to be chosen. The software developer could help out maybe. I will upload the current bin file shortly if you want to get back to the Arduino firmware.

se-bastiaan, 2024-05-07:
I've recorded the values received by the bridge on the bus during a single day. The 20/600 values do allow me to receive messages, but except for a few case none of those were sent by the switchboard at the front door:

```
20:43:08 {"code": 16, "addr": 25}
20:43:07 {"code": 17, "addr": 25}
19:49:08 {"code": 21, "addr": 16}
19:48:07 {"code": 16, "addr": 16}
19:47:12 {"code": 21, "addr": 16}
19:45:42 {"code": 16, "addr": 16}
19:36:03 {"code": 21, "addr": 16}
19:34:53 {"code": 16, "addr": 16}
19:28:27 {"code": 21, "addr": 16}
17:41:13 {"code": 21, "addr": 29}
17:25:22 {"code": 18, "addr": 9}
17:25:18 {"code": 16, "addr": 9}
17:25:11 {"code": 17, "addr": 9}
17:12:09 {"code": 18, "addr": 45}
17:12:02 {"code": 16, "addr": 45}
17:11:59 {"code": 17, "addr": 45}
16:13:42 {"code": 21, "addr": 41}
16:12:34 {"code": 16, "addr": 41}
16:10:42 {"code": 16, "addr": 2}
16:10:36 {"code": 21, "addr": 2}
16:07:05 {"code": 63, "addr": 255}
16:06:54 {"code": 18, "addr": 31}
16:06:51 {"code": 16, "addr": 31}
16:06:47 {"code": 49, "addr": 31}
16:06:47 {"code": 17, "addr": 31}
15:23:21 {"code": 16, "addr": 8}
15:23:08 {"code": 63, "addr": 255}
15:22:0 {"code": 50, "addr": 8}
```

Now the past few days I have slightly decreased the voltage value, and I have so far settled on 20/300. And thanks to one of my neighbours throwing a Eurovision viewing party I have been able to test those values extensively in the past 30 minutes:

```
20:23:28 {"code": 21, "addr": 16}
20:22:40 {"code": 63, "addr": 255}
20:22:29 {"code": 16, "addr": 16}
20:22:19 {"code": 50, "addr": 16}
20:19:18 {"code": 21, "addr": 16}
20:18:31 {"code": 63, "addr": 255}
20:18:20 {"code": 16, "addr": 16}
20:18:12 {"code": 50, "addr": 16}
20:12:07 {"code": 21, "addr": 18}
20:11:16 {"code": 63, "addr": 255}
20:11:05 {"code": 16, "addr": 18}
20:10:56 {"code": 50, "addr": 18}
20:07:26 {"code": 21, "addr": 16}
20:06:20 {"code": 16, "addr": 16}
20:06:11 {"code": 50, "addr": 16}
19:53:25 {"code": 63, "addr": 255}
19:53:14 {"code": 16, "addr": 16}
```

Elektroarzt, 2024-05-08:
Thanks for sharing your insights (and thanks to the neighbor with address 16 😂)

LaurensdeGraaff, 2024-05-09:
Back on the official firmware. Tried the default settings and 25/100. Both nothing

```
Comp Voltage:100
Gain:25
Intercom Address:12
1
Resistor value:
4166.00Percentage:
3.84Percentage value
5write Pot5Voltage to set:
100Resistor Value:
3125.00Resistor value:
3125.00Percentage:
2.80Percentage value
4write Pot4Attempting MQTT connection...connected
```

Is it a game of testing values till you get it right or do you have tips/suggestions?
I'm living on the 4th floor, so quite high up.

Elektroarzt, 2024-05-10:
I wrote a short [how-to](https://github.com/Elektroarzt/simplebus2-mqtt-bridge/blob/main/software/tuning%20process.md) for the tuning process. This should help.

mgiugliano, 2024-05-10:
I would love to help. However I am complete newbie for MQTT and I am trying to use io.adafruit. I did create (from the Dashboard) a feed with the name SimpleBus but I see no heartbeat, let alone messages. Any hints to go to the next step would be immensely appreciated.

I wonder whether the Arduino IDE serial monitor could be of help in this very initial phase of installation, although I am a bit hesitant to connect my laptop via USB to the bridge, while the device is also connected to the (35mV) simplebus lines.

mgiugliano, 2024-05-10:
Thank you!!!!

Some progress: I disconnected the bridge from the (hw) SimpleBus and connected to my laptop. I do get Serial Monitor debug messages! I can now debug the MQTT part..

I get
`Attempting MQTT connection...failed, rc=5 try again in 5 seconds`

This has been reported [here](https://github.com/knolleary/pubsubclient/issues/291#issuecomment-354668921) pointing to an authentication error. I replaced the password with the AIO_Key, but I get the same error.

I have to play with the pubsubclient library and Adafruit. This has nothing to do with the simpleBus bridge, I realized.

Closed 2024-09-07.

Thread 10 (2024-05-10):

SW: add instructions to configure IDE

mgiugliano, 2024-05-10:
I am deeply sorry for my stupid request. I would love to tinker the code (currently adding some delay() statement). I failed to have my Arduino IDE up and running to compile and flash the firmware on the microcontroller.

I understand Arduino IDE (or VSCode extension) is not the one in use/recommended. Even creating an empty software.ino file (i.e. `touch software.ino`) in the folder 'software', the IDE does not like the location of ./lib etc. etc.

Any hints would be helpful. I volunteer to create step by step instructions for newbie like me ;)

mgiugliano, 2024-05-30:
:-(

Elektroarzt, 2024-05-30:
Hi Mike … I‘ve seen your request, but I’m „only“ the hardware developer. Gurkenflieger is the software guy. Maybe you ask again in the issue. I can’t really help you in this point … sorry.Best regards, ThomasAm 30.05.2024 um 13:22 schrieb Michele GIUGLIANO ***@***.***>:
:-(

—Reply to this email directly, view it on GitHub, or unsubscribe.You are receiving this because you are subscribed to this thread.Message ID: ***@***.***>

mgiugliano, 2024-05-30:
I would love @Gurkenflieger to be up and running recompiling the code. I apologize for my ignorance. I am really keen to contribute and collaborate.

A quick and dirty pointer to "how do I compile" would be fantastic !

mgiugliano, 2024-06-27:
@Gurkenflieger may I ask you to quickly go through the steps I noted down and concisely described below? They might be beneficial for other "beginners" like me who would love to contribute to this project.

Accept my apologies in advance for wasting your time: your feedback would be precious. My text, after your validation or correction, might be then added to some documentation in a simple README.txt file or part of a wiki page.

# How to contribute (firmware-wise)

- install Visual Studio Code: see [here](https://code.visualstudio.com/)
- install PlatformIO as an extension to VSCode: see [here](https://platformio.org/install/)
- restart VSCode
- click on PlatformIO icon, on the left toolbar
- Create a "New Project", selecting
	- "Seeed Studio XIAO ESP32C3" as Board, and
	- "Espidf" as Framework
(this procedure may take several minutes)

- copy main.cpp to the root folder of the New Project
- copy the content of lib/ to the root folder of the New Project

Note: your platformio.ini should (automatically) look like this:

[env:seeed_xiao_esp32c3]
platform = espressif32
board = seeed_xiao_esp32c3
framework = espidf

- On top right button, shaped as a thick mark, select "Build". You should have an output similar to the one below (in a terminal window that will be spawn in the bottom part of the VSCode window):

[...]
Creating esp32c3 image...
Merged 2 ELF sections
Successfully created esp32c3 image.
Linking .pio/build/seeed_xiao_esp32c3/firmware.elf
Retrieving maximum program size .pio/build/seeed_xiao_esp32c3/firmware.elf
Checking size .pio/build/seeed_xiao_esp32c3/firmware.elf
Advanced Memory Usage is available via "PlatformIO Home > Project Inspect"
RAM:   [          ]   2.6% (used 8652 bytes from 327680 bytes)
Flash: [==        ]  17.1% (used 179378 bytes from 1048576 bytes)
Building .pio/build/seeed_xiao_esp32c3/firmware.bin
esptool.py v4.5.1
Creating esp32c3 image...
Merged 2 ELF sections
Successfully created esp32c3 image.
===================================================== [SUCCESS] Took 26.93 seconds =====================================================
 *  Terminal will be reused by tasks, press any key to close it.

Gurkenflieger, 2024-07-01:
Those steps are correct. You can also work with lib deps in the project.

Elektroarzt, 2024-07-01:
@mgiugliano if you like to release your information, please make a pull request for example for a file named 'IDE setup.md' or similar in the software folder containing your information. Please support future upcoming questions of the community concerning your content.
Thanks!

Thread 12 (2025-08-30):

BOM

j2025r, 2025-08-30:
Hi and thank you for your awesome work and for sharing it.

Would it be possible to share the actual BOM with all details, what you really bought?
The current BOM doesn't show things like voltage levels etc..

It would be very time saving if you could share the actual part numbers or distributor part numbers.

Thanks!

Elektroarzt, 2025-10-07:
Unfortunately there is no BOM or table with distributors or detailed parts information as I just used JLC part numbers, which can't be bought or shipped directly. Only solution for you would be opening the KiCAD project, read out the JLC numbers and find a corresponding distributor part, sorry.

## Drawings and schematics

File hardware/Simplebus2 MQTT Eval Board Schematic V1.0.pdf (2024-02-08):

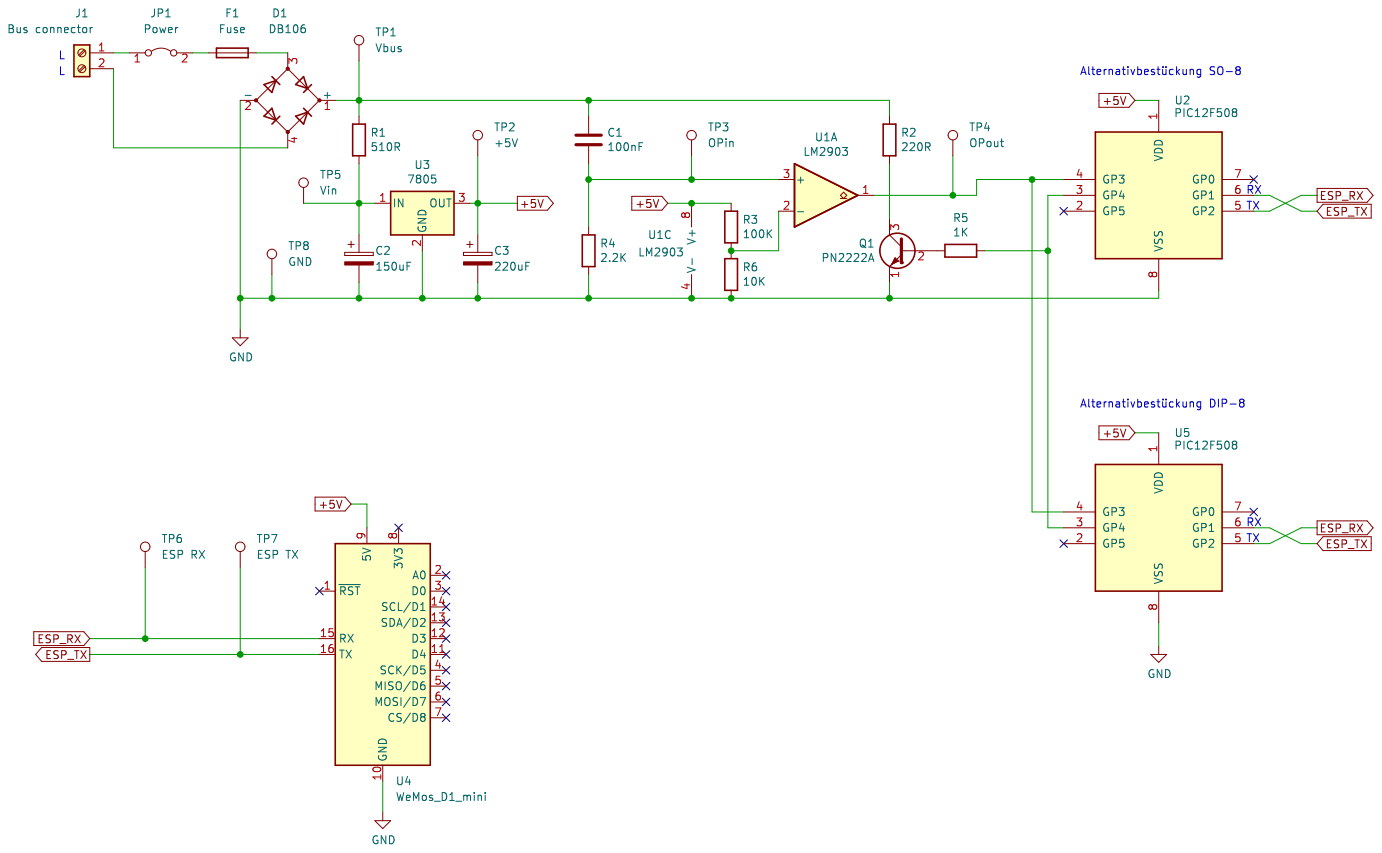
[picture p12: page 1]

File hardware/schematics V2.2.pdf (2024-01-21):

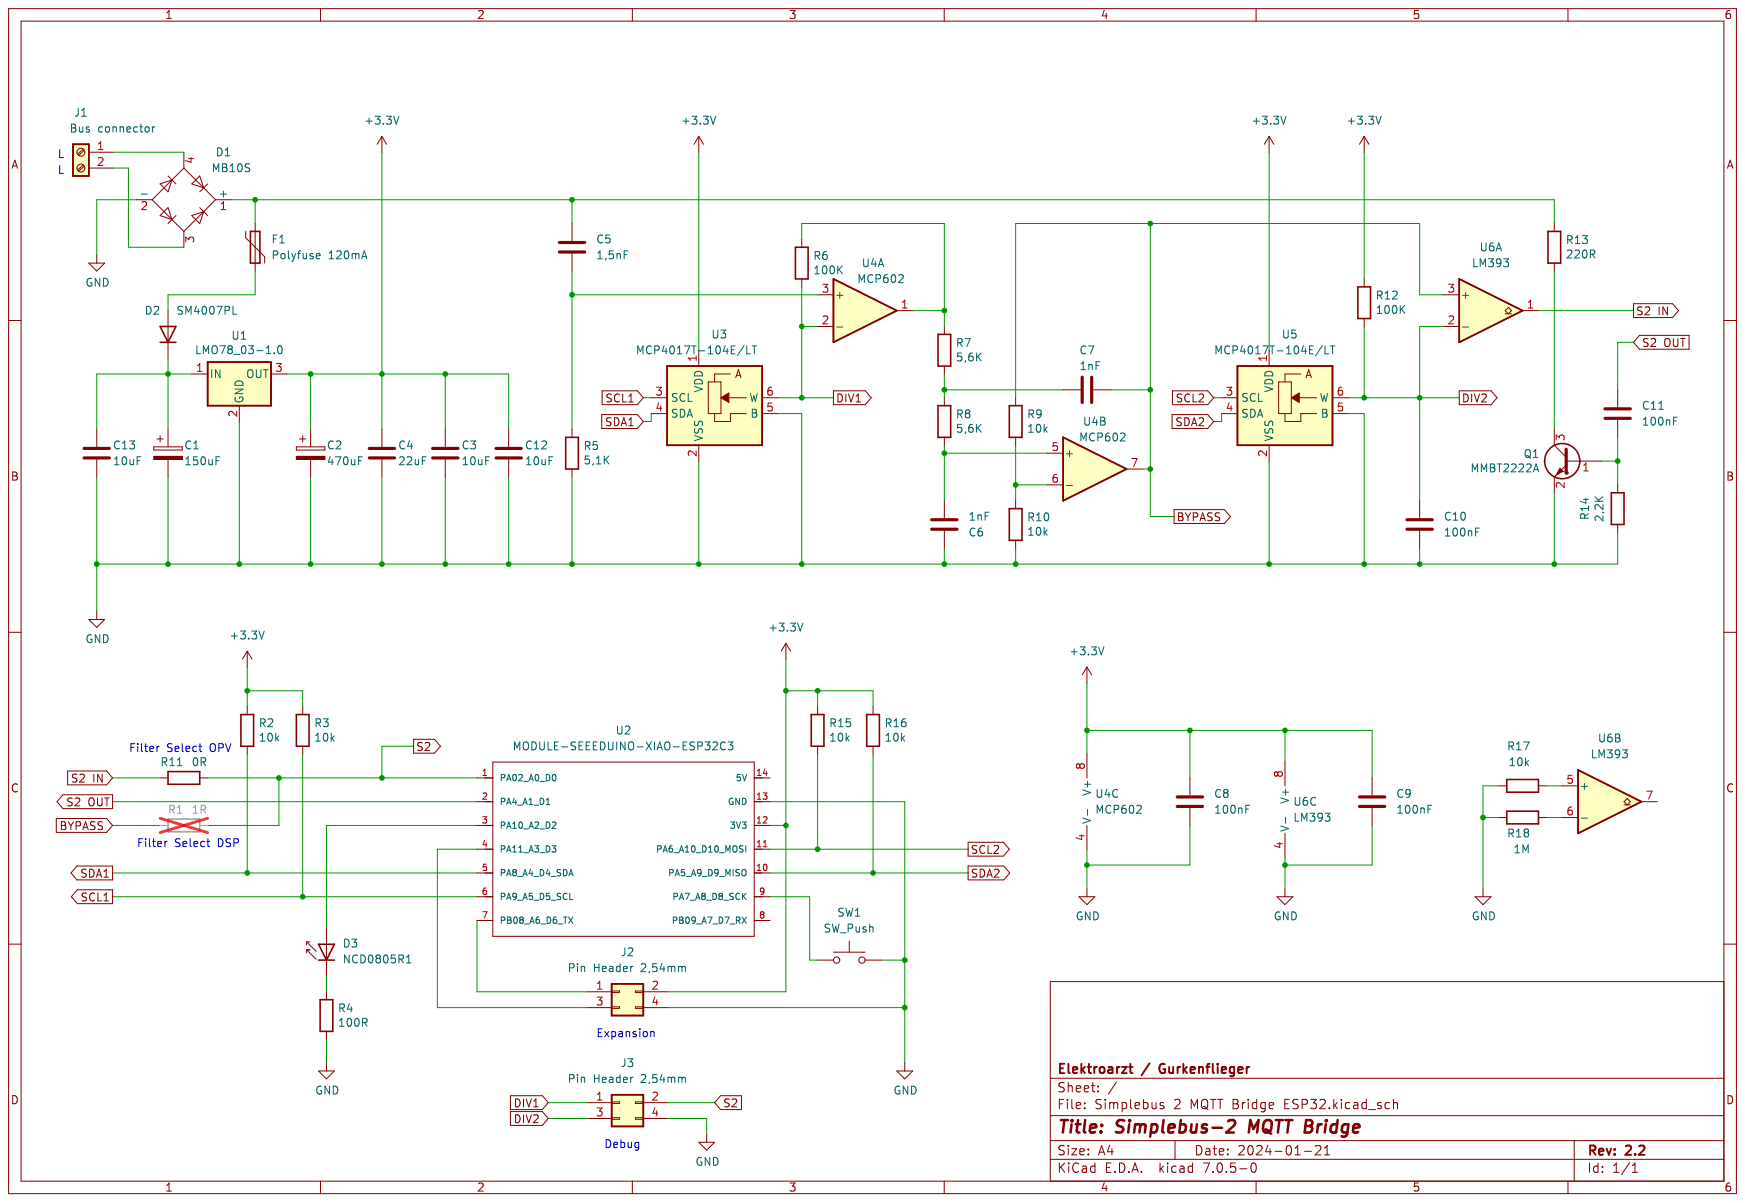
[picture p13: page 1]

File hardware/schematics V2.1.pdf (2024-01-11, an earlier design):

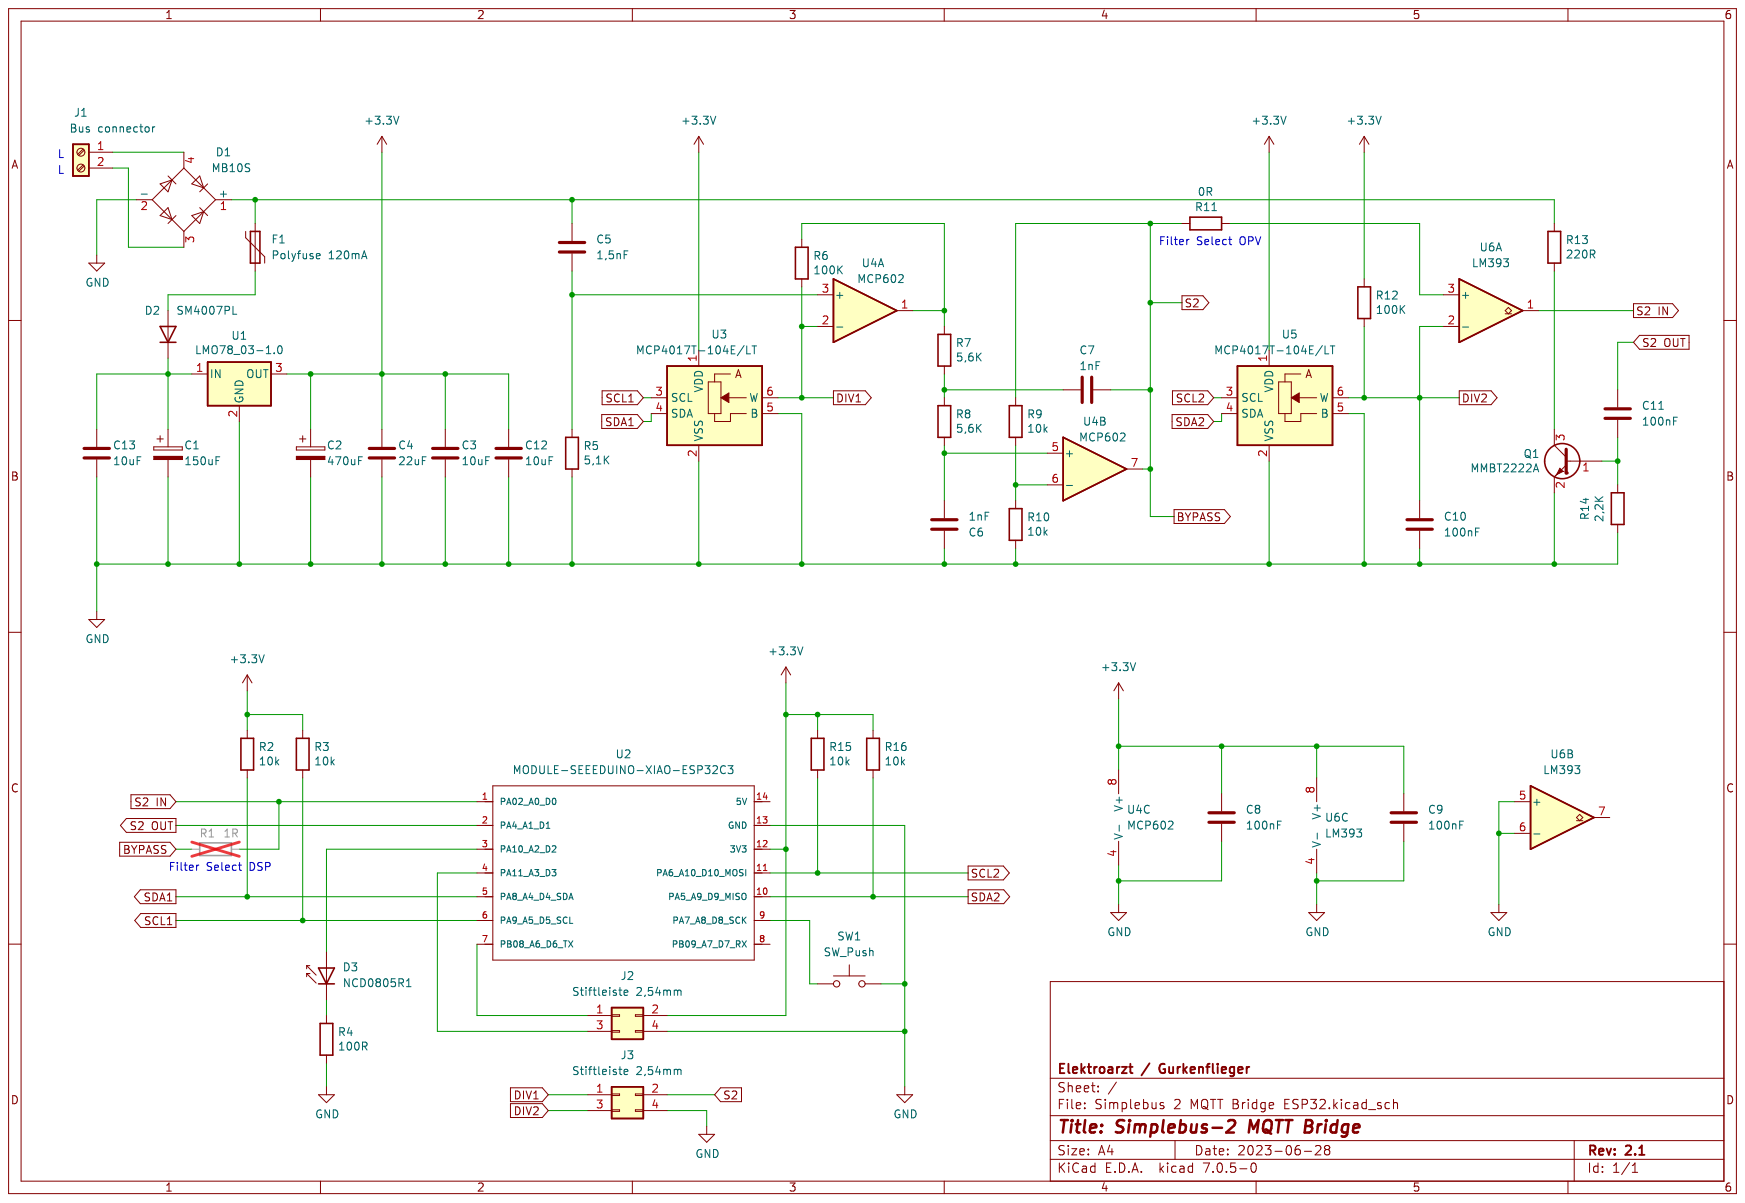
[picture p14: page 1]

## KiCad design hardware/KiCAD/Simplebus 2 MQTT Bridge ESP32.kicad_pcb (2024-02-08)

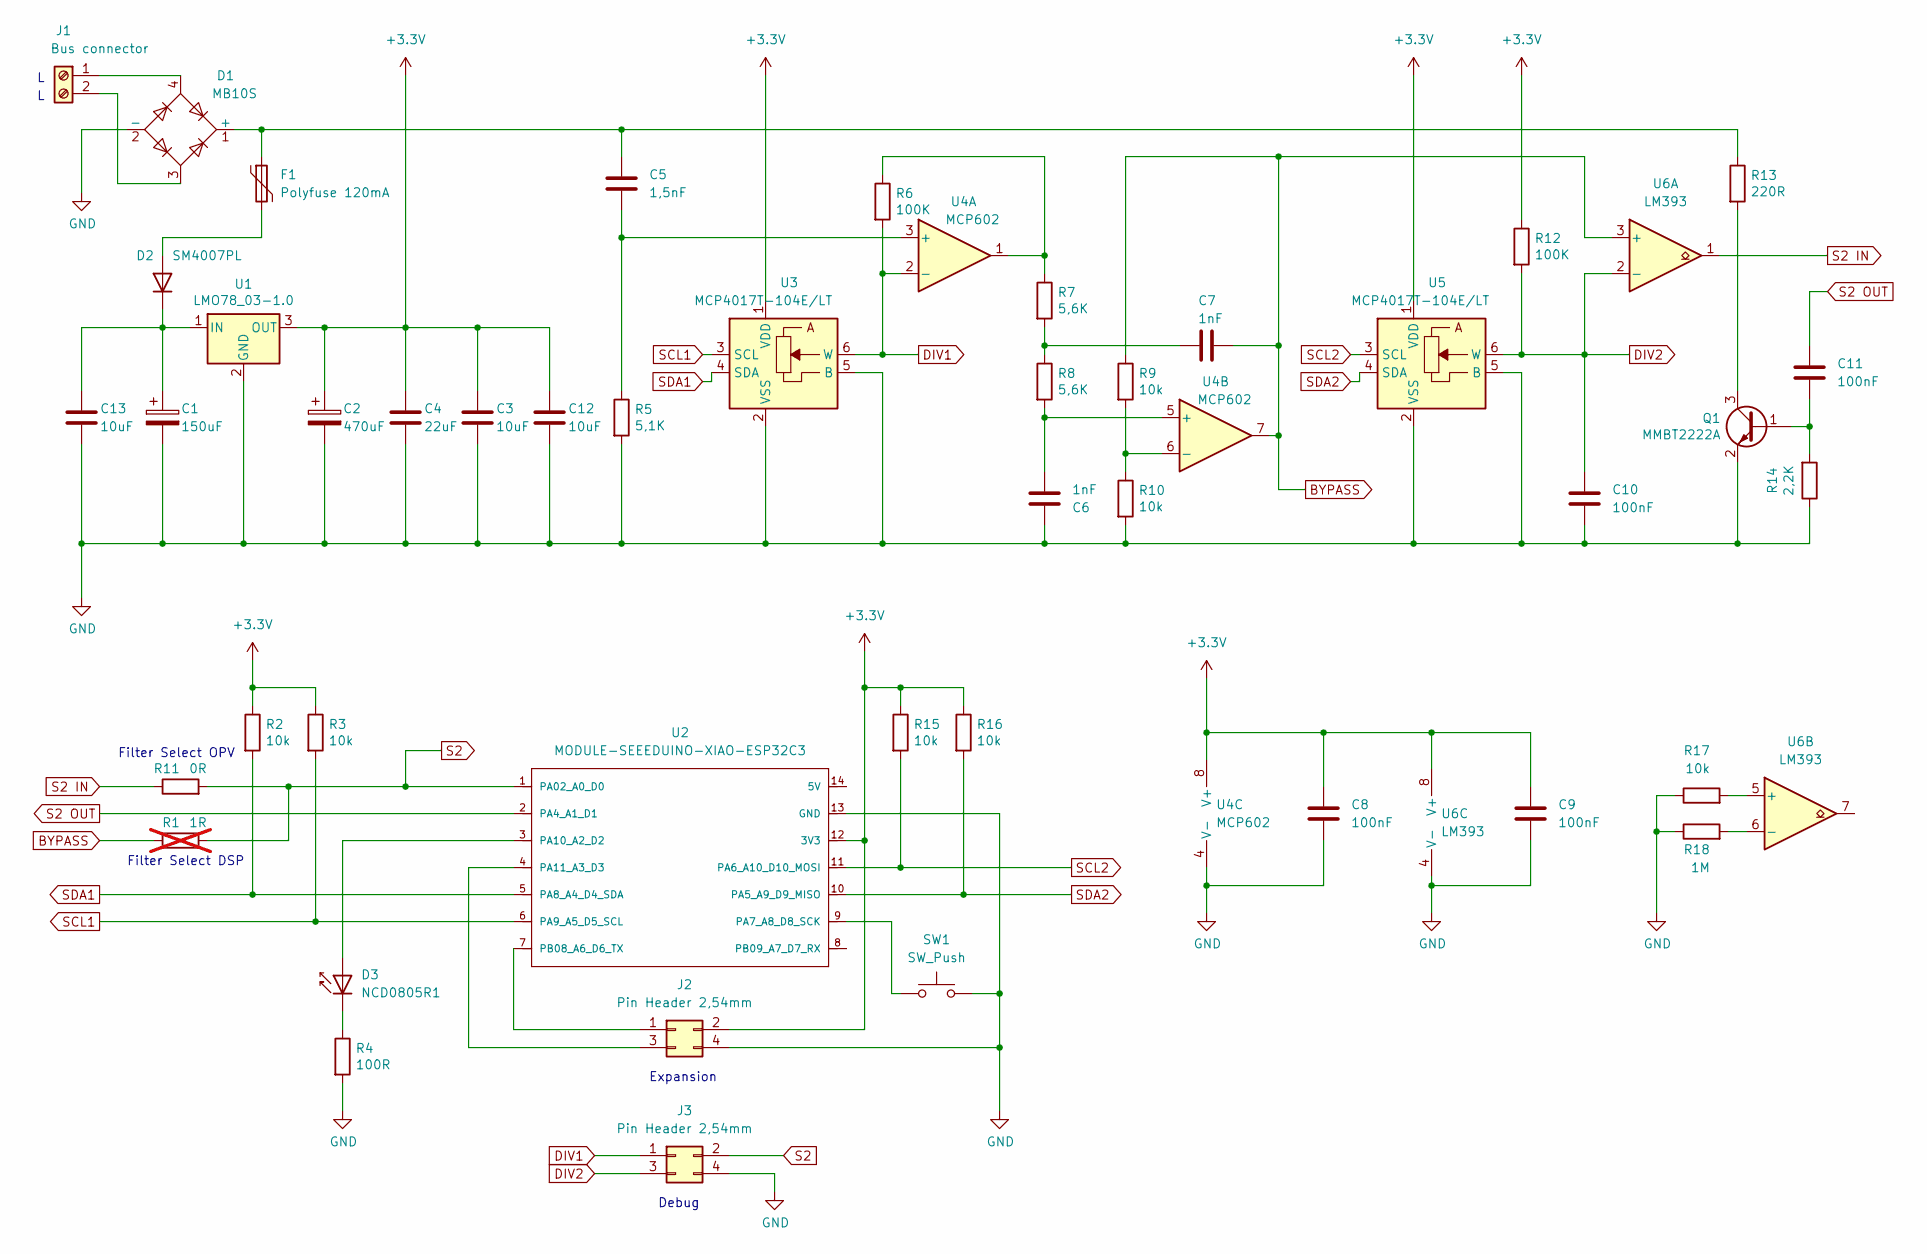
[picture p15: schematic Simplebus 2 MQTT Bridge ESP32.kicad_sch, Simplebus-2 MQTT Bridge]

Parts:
C1: 150uF; C_Elec_8x10.2; LCSC C87860
C2: 470uF; CP_Elec_6.3x7.7; LCSC C445248
C3, C12, C13: 10uF; C_1206_3216Metric_Pad1.33x1.80mm_HandSolder; LCSC C513774
C4: 22uF; C_1206_3216Metric_Pad1.33x1.80mm_HandSolder; LCSC C5672
C5: 1,5nF; C_0805_2012Metric_Pad1.18x1.45mm_HandSolder; LCSC C1717
C6, C7: 1nF; C_0805_2012Metric_Pad1.18x1.45mm_HandSolder; LCSC C46653
C8, C9, C10: 100nF; C_0805_2012Metric_Pad1.18x1.45mm_HandSolder; LCSC C28233
C11: 100nF; C_0805_2012Metric_Pad1.18x1.45mm_HandSolder; LCSC C49678
D1: MB10S; SOIC245P670X290-4N; LCSC C2488
D2: SM4007PL; D_SOD-123F; LCSC C64898
D3: NCD0805R1; LED_0805_2012Metric_Pad1.15x1.40mm_HandSolder; LCSC C84256
F1: Polyfuse 120mA; C_1206_3216Metric_Pad1.33x1.80mm_HandSolder; LCSC C20982
J1: Bus connector; PinHeader_1x02_P5.75mm_Vertical
J2, J3: Pin Header 2,54mm; PinHeader_2x02_P2.54mm_Vertical
Q1: MMBT2222A; SOT-23; LCSC C8512
R1: 1R; R_0805_2012Metric_Pad1.20x1.40mm_HandSolder; LCSC C25271; not fitted
R2, R3, R9, R10, R15, R16, R17: 10k; R_0805_2012Metric_Pad1.20x1.40mm_HandSolder; LCSC C17414
R4: 100R; R_0805_2012Metric_Pad1.20x1.40mm_HandSolder; LCSC C17408
R5: 5,1K; R_0805_2012Metric_Pad1.20x1.40mm_HandSolder; LCSC C27834
R6, R12: 100K; R_0805_2012Metric_Pad1.20x1.40mm_HandSolder; LCSC C149504
R7, R8: 5,6K; R_0805_2012Metric_Pad1.20x1.40mm_HandSolder; LCSC C4382
R11: 0R; R_0805_2012Metric_Pad1.20x1.40mm_HandSolder; LCSC C17477
R13: 220R; R_0805_2012Metric_Pad1.20x1.40mm_HandSolder; LCSC C17557
R14: 2,2K; R_0805_2012Metric_Pad1.20x1.40mm_HandSolder; LCSC C17520
R18: 1M; R_0805_2012Metric_Pad1.20x1.40mm_HandSolder; LCSC C17514
SW1: SW_Push; SW_Push_1P1T_XKB_TS-1187A; LCSC C318884
U1: LMO78_03-1.0; SIP-3 GAPTEC LMO78_xx-x.x
U2: MODULE-SEEEDUINO-XIAO-ESP32C3; MODULE14P-THT-2.54-21X17.8MM
U3, U5: MCP4017T-104E/LT; SOT-363_SC-70-6; LCSC C510890
U4: MCP602; SOIC-8_3.9x4.9mm_P1.27mm; LCSC C29605
U6: LM393; SOIC-8_3.9x4.9mm_P1.27mm; LCSC C7955

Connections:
+3.3V: C2.1, C3.1, C4.1, C8.1, C9.1, C12.1, J2.2, R2.1, R3.1, R12.1, R15.1, R16.1, U1.3 (OUT), U2.12 (3V3), U3.1 (VDD), U4.8 (V+), U5.1 (VDD), U6.8 (V+)
BYPASS: C7.1, R1.1, R9.1, U4.7, U6.3 (+)
DIV1: J3.1, R6.2, U3.6 (W), U4.2 (-)
DIV2: C10.1, J3.3, R12.2, U5.6 (W), U6.2 (-)
GND: C1.2, C2.2, C3.2, C4.2, C6.2, C8.2, C9.2, C10.2, C12.2, C13.2, D1.2 (-), J2.4, J3.4, Q1.2 (E), R4.2, R5.2, R10.2, R14.1, R17.1, R18.1, SW1.2, U1.2 (GND), U2.13 (GND), U3.2 (VSS), U3.5 (B), U4.4 (V-), U5.2 (VSS), U5.5 (B), U6.4 (V-)
unnamed: C7.2, R7.2, R8.1
unnamed: C5.1, D1.1 (+), F1.1, R13.1
unnamed: D2.2 (A), F1.2
unnamed: C1.1, C13.1, D2.1 (K), U1.1 (IN)
unnamed: D3.2 (A), U2.3 (PA10_A2_D2)
unnamed: D3.1 (K), R4.1
unnamed: D1.4, J1.1
unnamed: D1.3, J1.2
unnamed: J2.1, U2.7 (PB08_A6_D6_TX)
unnamed: J2.3, U2.4 (PA11_A3_D3)
unnamed: C11.2, Q1.1 (B), R14.2
unnamed: Q1.3 (C), R13.2
unnamed: R6.1, R7.1, U4.1
unnamed: SW1.1, U2.9 (PA7_A8_D8_SCK)
unnamed: C5.2, R5.1, U4.3 (+)
unnamed: C6.1, R8.2, U4.5 (+)
unnamed: R9.2, R10.1, U4.6 (-)
unnamed: R17.2, U6.5 (+)
unnamed: R18.2, U6.6 (-)
S2: J3.2, R1.2, R11.2, U2.1 (PA02_A0_D0)
S2 IN: R11.1, U6.1
S2 OUT: C11.1, U2.2 (PA4_A1_D1)
SCL1: R3.2, U2.6 (PA9_A5_D5_SCL), U3.3 (SCL)
SCL2: R15.2, U2.11 (PA6_A10_D10_MOSI), U5.3 (SCL)
SDA1: R2.2, U2.5 (PA8_A4_D4_SDA), U3.4 (SDA)
SDA2: R16.2, U2.10 (PA5_A9_D9_MISO), U5.4 (SDA)

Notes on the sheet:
Debug
Filter Select DSP
Expansion
Filter Select OPV

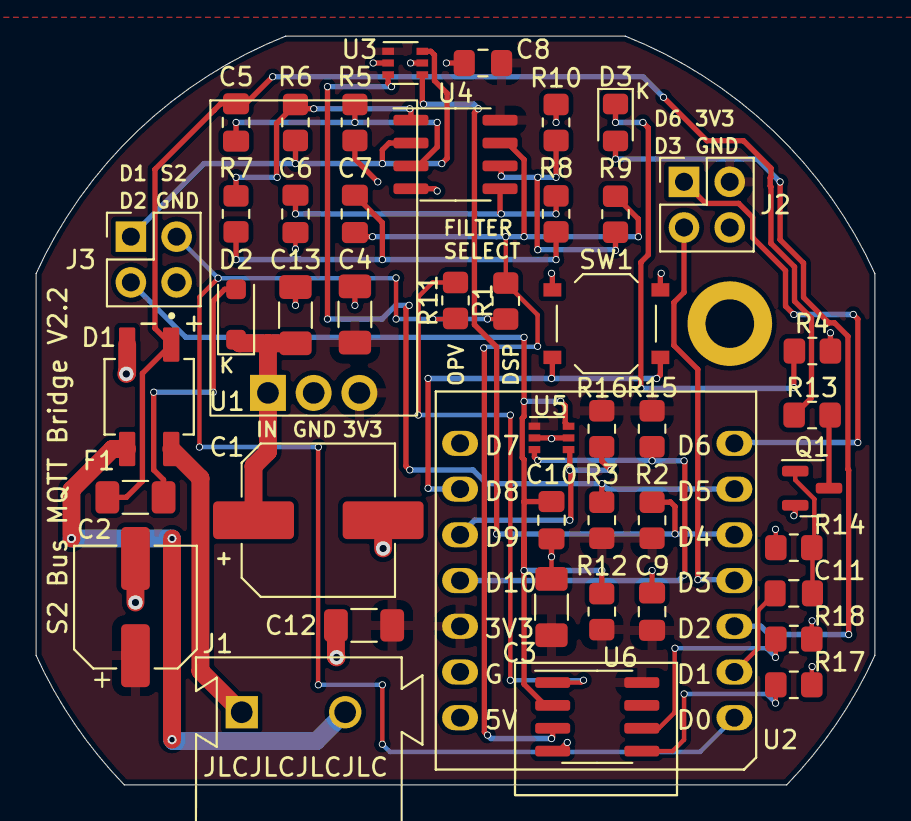
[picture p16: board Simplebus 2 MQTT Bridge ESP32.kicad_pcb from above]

Board: 2 copper layers, 46.6 x 41.6 mm, 46 parts (0 on the bottom side), 31 nets.

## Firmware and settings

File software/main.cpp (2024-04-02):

#include <Arduino.h>
#include <WiFi.h>
#include <WiFiManager.h> 
#include <PubSubClient.h>  
#include <time.h>
#include <Wire.h>
#include "soc/soc.h"
#include "soc/rtc_cntl_reg.h"
#include <PinButton.h>
#include <Debounce.h>
#include <EEPROM.h>

void function_ISR();
bool interruptActive = false;
bool teachInActive = false;
unsigned long teachInTimeActivated;

struct Settings {
  char mqttServer[40];
  char mqttUser[40];
  char mqttPassword[40];
  int gain;
  int compVoltLvl;
  bool filter;
  bool ringAutomation;
  int intercomAddress;
} mySettings;
WiFiClient espClient;
PubSubClient client(espClient);
long lastMsg = 0;
char msg[50];
int value = 0;
volatile int messageCode = 0;
bool messageReceived = false;

bool ringToOpenStarted = false;
unsigned int ringToOpenMillis = 45*60*1000;
unsigned int ringToOpenMillisStart = 0;
volatile bool pinTriggered = false;
int lastState = LOW;  
int currentState;    
unsigned long pressedTime  = 0;
unsigned long releasedTime = 0;
unsigned long lastHeartbeatMillis = 0;




///////////////////////////////////////////////////////////////////////////////
// Message cod
//
// Call Addrress from the intercom

// Hardware pin definition
#define LEDPIN 4
#define INTERCOM_READ_PIN 2
#define INTERCOM_WRITE_PIN 3
#define BUTTONPIN 8
#define SDA_1 6
#define SCL_1 7
#define SDA_2 9
#define SCL_2 10
// Hardware Settings
#define MCP4017_MAX_RESISTANCE 100000
#define MCP4017_I2C_ADDRESS  0x2F
#define I2C_FREQ 100000
#define OPV_FIXED_GAIN_RESISTOR 100000

// Sent from intercoms to call the main switchboard.
#define MSG_CALL_TO_MAIN_SWITCHBOARD         8

// Sent from intercoms to call the caretaker phone (K).
#define MSG_CALL_CARETAKER_DOOR_ENTRY_PHONE  9

// Open building's entry door (AP). Sent when the intercom's open door button 
// is pushed. User ID tells who's opening the door.
#define MSG_OPEN_DOOR                       16

// Sent when the user hooks off the intercom's handset.
#define MSG_HOOK_OFF                        17

// Sent when the user hooks on the intercom's handset.
#define MSG_HOOK_ON                         18

// Send from intercoms to call the secondary switchboard. In model the 
// secondary button can be configured to send this message by setting the JP1
// jumper to position C.
#define MSG_CALL_TO_SECONDARY_SWITCHBOARD   19

// Turns on the video camera and the intercom's screen (AI).
#define MSG_CAMERA_ON                       20

// Sent when the external switch connected to the CFP terminals is closed.
#define MSG_CALL_FROM_FLOOR_DOOR            21

// Sent by one intercom to call other intercomms (INT).
#define MSG_CALL_INTERCOM                   24

// After sending MSG_CALL_INTERCOM three consecutive
// MSG_CALL_INTERCOM_RESPONSE are sent.
#define MSG_CALL_INTERCOM_RESPONSE          26

// Activates a generic actuator. In model the secondary button can be
// configured to send this message by setting the JP1 jumper to position A.
#define MSG_GENERIC_ACTUATOR                29

// High prioritary call to main switchboard (PAN).
#define MSG_HIGH_PRIO_CALL_TO_MAIN_SWITCHBOARD  30

// Sent from switchboard for calling an intercom.
#define MSG_CALL_FROM_SWITCHBOARD_1         32

// After sending this message I got a MSG_HOOK_ON, but only once. What does
// this mean?.
#define MSG_UNKNOWN_1                       33


#define MSG_CALL_FROM_SWITCHBOARD_2             37
#define MSG_CALL_FROM_SWITCHBOARD_3             42
#define MSG_CALL_FROM_SWITCHBOARD_4             43
#define MSG_CALL_FROM_SWITCHBOARD_5_SCREEN_ON   45


// Sent when someone calls at the building's entry. The ring tone is played
// once per each message, this message is usually sent two times, followed by 
// MSG_CALL_FROM_ENTRY_DOOR_SCREEN_ON.
#define MSG_CALL_FROM_ENTRY_DOOR            48

// Sent when the screen is turned off ?????
#define MSG_SCREEN_OFF                      49

// Similar to MSG_RING_TONE but also makes the intercom turn on the video 
// screen.
#define MSG_CALL_FROM_ENTRY_DOOR_SCREEN_ON  50


#define MSG_START_BLINKING_OPEN_DOOR_BTN    51
#define MSG_STOP_BLINKING_OPEN_DOOR_BTN     52


///////////////////////////////////////////////////////////////////////////////
// Global variables
// 



// Last time the door was opened, either with Blynk or the input button.

volatile bool messageOk = false;
  
unsigned long lastOpenDoorTime;
unsigned long pauseTime;
unsigned long startTime;
bool pauseTimeMeasured;
bool pauseTimeStart;
int count;
//PinButton settupButton(BUTTONPIN, INPUT_PULLUP,);
Debounce Button(BUTTONPIN);

int writeStringToEEPROM(int addrOffset, const char *strToWrite)
{
  byte len = strlen(strToWrite);
  EEPROM.put(addrOffset, len);
  for (int i = 0; i < len; i++)
  {
    EEPROM.put(addrOffset + 1 + i, strToWrite[i]);
  }
  
  return addrOffset + 1 + len;
}
int readStringFromEEPROM(int addrOffset, char *strToRead)
{
  int newStrLen = EEPROM.read(addrOffset);
  for (int i = 0; i < newStrLen; i++)
  {
    strToRead[i] = EEPROM.read(addrOffset + 1 + i);
  }
  strToRead[newStrLen] = '\0'; 
  
  return addrOffset + 1 + newStrLen;
}
void saveSettings() {
  EEPROM.put(0,mySettings);
  EEPROM.commit();
}
void loadSettings() {
  EEPROM.get(0,mySettings);
  // compVoltLvl = EEPROM.read(str3Offset+2);
  Serial.println(String(mySettings.mqttServer));
  Serial.println(String(mySettings.mqttUser));
  Serial.println(String(mySettings.mqttPassword));
  Serial.println(mySettings.gain);
  Serial.println(mySettings.compVoltLvl);
}
bool structInitialized() {
  return   mySettings.compVoltLvl != 0 && mySettings.gain != 0 && sizeof(mySettings.mqttPassword) > 1 && sizeof(mySettings.mqttServer) > 1 && sizeof(mySettings.mqttPassword)>1;
}
boolean isNumeric(String str) {
    unsigned int stringLength = str.length();
    if (stringLength == 0) {
        return false;
    }
    for(unsigned int i = 0; i < stringLength; ++i) {
        if (isDigit(str.charAt(i))) {
            continue;
        }
        return false;
    }
    return true;
}
bool shouldSaveConfig = false;

void setupI2C(int i2cNumber) {
  int sclPin = -1;
  int sdaPin = -1;
  switch(i2cNumber) {
    case 1: {
      sdaPin = SDA_1;
      sclPin = SCL_1;
      break;
    }
    case 2: {
      sdaPin = SDA_2;
      sclPin = SCL_2;
      break;
    }
    default:{
      break;
    }
  }
  Wire.begin(sdaPin, sclPin, I2C_FREQ);
  Wire.beginTransmission(0b111111111);
  Wire.endTransmission();
}

void setPotValue(byte byteValue) {
  Serial.print("write Pot");
  Serial.print(byteValue);

  const uint8_t reg = byteValue & 0x7F;
  //Serial.print(reg);
  Wire.beginTransmission(MCP4017_I2C_ADDRESS);
  Wire.write(byteValue);
  Wire.endTransmission();
  Wire.end();
}

void setPotPercentage(float percentage) {
  if(percentage < 0 || percentage > 100) {
    return;
  }
  int value = round((float(percentage)/100.0) * 127.0);
  Serial.println("Percentage value");
  Serial.print(value);
  setPotValue(value);
 
}

void setPotResistance(float resistance) {
  Serial.println("Resistor value:");
  Serial.print(resistance);
  if(resistance < 0 || resistance > MCP4017_MAX_RESISTANCE) {
    return;
  }
  float percentageToSet = (float(resistance-325)/float(MCP4017_MAX_RESISTANCE)) * 100.0;
  Serial.println("Percentage:");
  Serial.print(percentageToSet);
  setPotPercentage(percentageToSet);
}

//set gain factor of the OPV
void setOPVGain(int gain) {
  //Gain = 1+(R2/R1)
  if(gain < 2) {
    return;
  }
  float resistorValue = OPV_FIXED_GAIN_RESISTOR/(gain-1);
  setupI2C(1);
  setPotResistance(resistorValue);
}

//set ref voltage of the comparator in [mV]
void setComparatorVoltageLimit(int voltage) {
  Serial.println("Voltage to set:");
  Serial.print(voltage);
  if(voltage < 100 || voltage > 1500) {
    return;
  }
  setupI2C(2);
  float resistorValue = (float(voltage) * float(OPV_FIXED_GAIN_RESISTOR))/(3300.0-float(voltage));
  Serial.println("Resistor Value:");
  Serial.print(resistorValue);
  setPotResistance(resistorValue);
}

void intToBinary(unsigned int input,int startPos,int noOfBits, int* bits) {
  unsigned int mask = 1;
  //static int bits [noOfBits];
  int zeroedStartPos = startPos-1;
  for(int i = startPos; i < noOfBits+startPos; i++) {
    bits[i] = (input & (1<<(i-startPos))) != 0;
  }
}

unsigned int binaryToInt(int startPos, int numOfBits, int binaryArray []) {
  unsigned int integer = 0;
  unsigned int mask = 1;
  for(int i = startPos; i < numOfBits+startPos; i++) {
    if(binaryArray[i]) integer |= mask;
    mask = mask << 1;
  }
  return integer;
}

void setPowerSavings() {
  Serial.print("CPU Freq:");
  Serial.println(getCpuFrequencyMhz());
  setCpuFrequencyMhz(80);
  Serial.print("CPU Freq:");
  Serial.println(getCpuFrequencyMhz());
}
void sendPWM() {
  ledcWrite(0, 50);
  delay(3);
  ledcWrite(0,0);
}
void sendMessage(bool bitToSend) {
  if(bitToSend) {
    sendPWM();
    delay(6);
    
  } else {
    sendPWM();
    delay(3);
  }
}

void sendMessageStart() {
  sendPWM();
  delay(17);
}

void writeMessageToIntercom(int msgCode, int msgAddr) {
  detachInterrupt(INTERCOM_READ_PIN);
  if(msgCode = MSG_OPEN_DOOR) {
    lastOpenDoorTime = millis();
  }  
  int msgArray [18];
  int checksum = 0;

  checksum += __builtin_popcount(msgCode);
  checksum += __builtin_popcount(msgAddr);
  Serial.print(checksum);
  Serial.println(" ");
  intToBinary(msgCode, 0, 6, msgArray );
  intToBinary(msgAddr, 6, 8, msgArray );
  intToBinary(checksum, 14, 4, msgArray );
  sendMessageStart();
  for(int i = 0; i < 18; i++) {
    sendMessage(msgArray[i]);
  }
  sendPWM();
  attachInterrupt(INTERCOM_READ_PIN, function_ISR, RISING);
 
}
void startStopRingToOpen(bool start) {
  if(start) {
    client.publish("SimpleBus/RingToOpenStatus", "ON");
  } else {
    client.publish("SimpleBus/RingToOpenStatus", "OFF");
  }
  ringToOpenStarted = start;
  
}
static unsigned long lastInterrupt = 0;
static int messagePositon = 0;
static int messageBitArray [18];
static bool messageStarted  = false;
static bool busHigh = false;
static unsigned long lastPauseTime = 0;

void processInterrupt() {
  unsigned long currentInterrupt = micros();
  unsigned long pauseTime = 0;
  //Serial.print("Processing ");
  if(true) { //currentInterrupt - lastInterrupt < 100 && currentInterrupt - lastInterrupt > 20
    pauseTime  = currentInterrupt - lastPauseTime;
    
    //Serial.println(pauseTime);
      
    if(pauseTime > 18000 && messageStarted) {
    messageStarted = false;
      //Serial.print("No Start Message Detected");
      
    }
  
    if(pauseTime >= 16000 && pauseTime <= 18000) {
      messageStarted = true;
      messagePositon = 0; 
    } 
        
      if(messageStarted) {
      
        switch(pauseTime) {
          case 2000 ... 4900: {
            count++;
            messageBitArray[messagePositon] = 0;
            ///Serial.print("0");
            messagePositon++;
            
            break;
          }
          case 5000 ... 9000: {
            count++;
            //Serial.print("1");
            messageBitArray[messagePositon] = 1;
            messagePositon++;
            
            
            break;
          }
          default:{
            break;
          }
        }
        if(messagePositon == 18) { 
          messageStarted = false;
          unsigned int msgCode = binaryToInt(0, 6, messageBitArray);
          //Serial.println(msgCode);
          unsigned int msgAddr = binaryToInt(6, 8, messageBitArray);
          //Serial.println(msgAddr);
          unsigned int msgChecksum = binaryToInt(14, 4, messageBitArray);
          int checksum = 0;
          checksum += __builtin_popcount(msgCode);
          checksum += __builtin_popcount(msgAddr);
          if(teachInActive) {
            mySettings.intercomAddress = msgAddr;
            saveSettings();
            teachInActive = false;
            digitalWrite(LEDPIN, LOW);
            ringToOpenStarted = true;
          }
          if(checksum == msgChecksum && msgAddr == mySettings.intercomAddress) {
            messageCode = msgCode;
            messageOk = true;
          } 
        }
    }
    lastPauseTime = currentInterrupt; 
  } else {
    

  }
  lastInterrupt = currentInterrupt;
  pinTriggered = false;
}
void processMessage(unsigned int msgCode) 
{
  switch (msgCode)
  {
    
    case MSG_CALL_TO_SECONDARY_SWITCHBOARD:
      break;
    case MSG_CALL_FROM_ENTRY_DOOR:
    case MSG_CALL_FROM_ENTRY_DOOR_SCREEN_ON:
      if(ringToOpenStarted) {
        // Waiting time in necessary otherwise the opening singal cant get through
        delay(2000);
        client.publish("SimpleBus/RingToOpenOpened", "ON");
        writeMessageToIntercom(MSG_OPEN_DOOR, mySettings.intercomAddress);
        startStopRingToOpen(false);
       
        
      } else {
        if ((lastOpenDoorTime > 0 && millis() - lastOpenDoorTime < 60000) && mySettings.ringAutomation) {
          // Wait for 2.5 seconds before opening the door. 
          delay(2000);
          client.publish("SimpleBus/RingToOpenOpened", "ON");
          writeMessageToIntercom(MSG_OPEN_DOOR, mySettings.intercomAddress);
          
        } else {
          delay(2000);
          client.publish("SimpleBus/EntryDoor", "ON");
        }
      }
      break;
    case MSG_CALL_FROM_FLOOR_DOOR:
      client.publish("SimpleBus/FloorDoor", "ON");
      break;
  case MSG_OPEN_DOOR:
    lastOpenDoorTime = millis();
    break;
  }

}

void function_ISR() {
  static unsigned long last_interrupt_time = 0;
  unsigned long interrupt_time = micros();
  // If interrupts come faster than 200ms, assume it's a bounce and ignore
  //this is a small filter which only accepts smaller a connected waveform
  if(!pinTriggered) {

      pinTriggered = true;
  }
  
  
 
 
  
  last_interrupt_time = interrupt_time;


}
void saveConfigCallback () {
  Serial.println("Should save config");
  shouldSaveConfig = true;
}
void addNullTermination(char *stringToSearch) {
  if(strchr(stringToSearch, '\0') == NULL ) {
    Serial.print(stringToSearch);
    Serial.print("Added null termination");
    stringToSearch[strlen(stringToSearch)] = '\0';

  }
}

void setup_wifi(bool autoconnect = true) {
  WRITE_PERI_REG(RTC_CNTL_BROWN_OUT_REG, 0);
  delay(10);
  WiFiManager wifiManager;
  wifiManager.setSaveConfigCallback(saveConfigCallback);
  wifiManager.setBreakAfterConfig(true);
  wifiManager.setConfigPortalTimeout(120);
  wifiManager.setConnectTimeout(60);
  WiFiManagerParameter custom_mqttServer("server", "mqtt server", mySettings.mqttServer, 40);
  wifiManager.addParameter(&custom_mqttServer);
  WiFiManagerParameter custom_mqtt_user("user", "mqtt user", mySettings.mqttUser, 40);
  wifiManager.addParameter(&custom_mqtt_user);
  WiFiManagerParameter custom_mqtt_password("password", "mqtt password", mySettings.mqttPassword, 40);
  wifiManager.addParameter(&custom_mqtt_password);
  char intercomAddress[2];
  itoa(mySettings.intercomAddress,intercomAddress,10);
  WiFiManagerParameter custom_intercomAddress("address", "Address Intercom", intercomAddress, 40);
  wifiManager.addParameter(&custom_intercomAddress);
  char gainChar[2];
  itoa(mySettings.gain,gainChar,10);
  WiFiManagerParameter custom_gain("Gain", "Gain", gainChar, 40);
  wifiManager.addParameter(&custom_gain);
  char compVoltChar[3];
  itoa(mySettings.compVoltLvl,compVoltChar,10);
  WiFiManagerParameter custom_voltage_level("voltagelevel", "Voltage level",compVoltChar, 40);
  wifiManager.addParameter(&custom_voltage_level); 
  char customhtmlFilter[24] = "type=\"checkbox\"";
  if (mySettings.filter) {
      strcat(customhtmlFilter, " checked");
  }
  WiFiManagerParameter custom_filter("filter", "Filter", "T", 2, customhtmlFilter, WFM_LABEL_AFTER);
  wifiManager.addParameter(&custom_filter);
  char customhtmlAutomation[24] = "type=\"checkbox\"";
  if (mySettings.ringAutomation) {
      strcat(customhtmlAutomation, " checked");
  }
  WiFiManagerParameter custom_automation("ringAutomation", "Open automation", "T", 2, customhtmlAutomation, WFM_LABEL_AFTER);
  wifiManager.addParameter(&custom_automation);

  if(autoconnect) {
    wifiManager.autoConnect("Config_MQTT_SimpleBus_2");
  } else  {
    wifiManager.startConfigPortal("Config_MQTT_SimpleBus_2");
  }
  if(shouldSaveConfig) {
    const char* voltageTmp = custom_voltage_level.getValue();
    const char* gainTmp = custom_gain.getValue();
    const char* intercomAddressTmp = custom_intercomAddress.getValue();
    strcpy(mySettings.mqttServer, custom_mqttServer.getValue());
    strcpy(mySettings.mqttUser, custom_mqtt_user.getValue());
    strcpy(mySettings.mqttPassword, custom_mqtt_password.getValue());
    Serial.println(custom_filter.getValue());
    mySettings.filter = (strncmp(custom_filter.getValue(), "T", 2) == 0);
    mySettings.ringAutomation = (strncmp(custom_automation.getValue(), "T", 2) == 0);
    
    Serial.println("Saving data to EEPROM");
    Serial.println("Server:"+String(mySettings.mqttServer));
    Serial.println("User:"+String(mySettings.mqttUser));
    Serial.println("MQTT Password:"+String(mySettings.mqttPassword));
    Serial.println("Comp Voltage:"+String(voltageTmp));
    Serial.println("Gain:"+String(gainTmp));
    Serial.println("Intercom Address:"+String(intercomAddressTmp));
    Serial.println( mySettings.ringAutomation);
    Serial.println( mySettings.filter);
    if(isNumeric(String(voltageTmp))) {
      mySettings.compVoltLvl = String(voltageTmp).toInt();
    } else {
      mySettings.compVoltLvl = 600;
    }
    if(isNumeric(String(gainTmp))) {
      mySettings.gain = String(gainTmp).toInt();
    } else {
      mySettings.gain = 20;
    }
    if(isNumeric(String(intercomAddressTmp))) {
      mySettings.intercomAddress = String(intercomAddressTmp).toInt();
    } else {
      mySettings.intercomAddress = 0;
    }
    saveSettings();
  }

  WiFi.setTxPower(WIFI_POWER_MINUS_1dBm);
  //WiFi.setSleep(true);
  WRITE_PERI_REG(RTC_CNTL_BROWN_OUT_REG, 1);
}
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
void loop()
{
  if(millis()-lastHeartbeatMillis >= 60000*5) {
    client.publish("SimpleBus/Heartbeat", "ON");
    lastHeartbeatMillis = millis();
  }
  currentState = Button.read();
  if(teachInActive) {
    long diffTimeTeachIn = millis() - teachInTimeActivated;
    if(diffTimeTeachIn > 180000) {
      teachInActive = false;
      digitalWrite(LEDPIN, LOW);
    } 
  }

  if(lastState == LOW && currentState == HIGH)        // button is pressed
    pressedTime = millis();
  else if(lastState == HIGH && currentState == LOW) { // button is released
    releasedTime = millis();

    long pressDuration = releasedTime - pressedTime;

    if( pressDuration < 1000 && pressDuration > 100 ) {
      pressDuration = 0;
     
      digitalWrite(LEDPIN, HIGH);
      setup_wifi(false);
      setOPVGain(mySettings.gain);
      setComparatorVoltageLimit(mySettings.compVoltLvl);
      digitalWrite(LEDPIN, LOW);
      if (!client.connected())
      {
        reconnect();
      }

    }
      
    if( pressDuration > 2000 && pressDuration < 5000 ) {
      pressDuration = 0;
      teachInTimeActivated = millis();
      teachInActive = !teachInActive;
      if(teachInActive) {
        digitalWrite(LEDPIN, HIGH);
        delay(500);
        digitalWrite(LEDPIN, LOW);
        delay(500);
        digitalWrite(LEDPIN, HIGH);
        delay(500);
        digitalWrite(LEDPIN, LOW);
        delay(500);
        digitalWrite(LEDPIN, HIGH);
      } else {
        digitalWrite(LEDPIN, LOW);
      }
      
    }
  }
  lastState = currentState;
  client.loop();
  
  if (!client.connected())
  {
    reconnect();
  }
  if(ringToOpenStarted) {
    if(millis() - ringToOpenMillisStart > ringToOpenMillis) {
      startStopRingToOpen(false);
    }
  }
  if(pinTriggered) {
    processInterrupt();
  }
  if(messageOk) {
    processMessage(messageCode);
    messageOk = false;
  }
}

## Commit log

2024-01-11 Added mechanics
    [Simplebus2 MQTT Bridge Bambu Lab Project.3mf]
2024-01-13 Rename Schematics V2.1.pdf
2024-01-20 Create DIP switch.jpeg
2024-01-21 Schematic and PCB V2.2
2024-02-08 Added KiCAD project
    [Simplebus 2 MQTT Bridge ESP32.kicad_pcb, Simplebus 2 MQTT Bridge ESP32.kicad_sch]
2024-02-13 I2C bugfix, bugfix SetRingToOpenTime, added teach in for intercom address
    Added teach in for intercom address with long press 2-3 seconds.
    Short press opens wifimanager
    [main.cpp]
2024-02-14 Added intercom adress to onfiguration
    [Simplebus2 MQTT Bridge Bambu Lab Project.3mf]
2024-02-17 Update Bambu Lab project
    [Simplebus2 MQTT Bridge Bambu Lab Project.3mf]
2024-03-01 Added libs and bugfixes
    +Works now on doors without a screen
    +Bugfix I2C resistor
    [main.cpp]
2024-03-13 Update main.cpp
    Bugfix i2c
    [main.cpp]
2024-03-18 Bugfix and tighter timings
    +Tighter Timings
    +Better noise reduction and filtering for longer high signals
    +Added teach in and wificonfig MQTT Command
    [main.cpp]
2024-03-23 Update README.md
    Updated pictures to new version of housing
2024-04-01 Update README.md
    MQTT Update
    + Heartbeat
    + Feedback if 'ring-to-open' opened the door
    + Reset ESP32
    Improved ring recognition
2024-04-01 Bugfix added missing MQTT commands
    Bugfix added missing MQTT commands
    [main.cpp]
2024-04-01 Minor bugfix
    +Heartbeat now sends directyl after Reboot one time
    [main.cpp]
2024-04-02 Bugfix teach in and configmode
    [main.cpp]
2024-04-02 New pictures after redesign of housing
2024-04-02 Remove SW filter, update standard gain / threshold
    - Removed software filter, was experimental and had no positive function
    - updated gain and threshold standard values to 20 / 600
2024-04-02 Update README.md
    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
2025-03-11 Added Housing for DIN Rail Mount
    [Housing Bottom Shell DIN Rail Mount.stl, Housing Bottom Shell Flush Mounted.stl]
2026-08-01 docs: update web UI screenshot for firmware 2.0.0
    Replace the README/setup screenshot with a current 2.0.0 status page
    (redacted broker host).
2026-08-01 docs: add Home Assistant entities screenshot to README
    Show MQTT discovery controls and sensors under the Home Assistant section.
